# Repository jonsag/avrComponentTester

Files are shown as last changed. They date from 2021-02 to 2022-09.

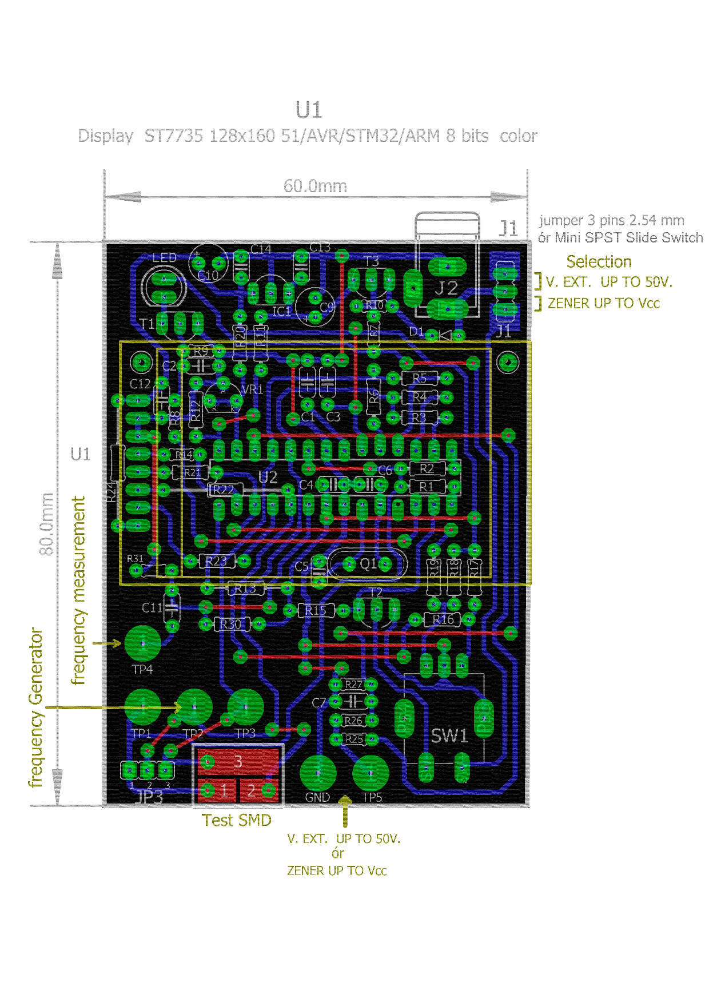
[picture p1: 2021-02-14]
Documents/PCB_mega328_ST7735/PCB single sided.jpg

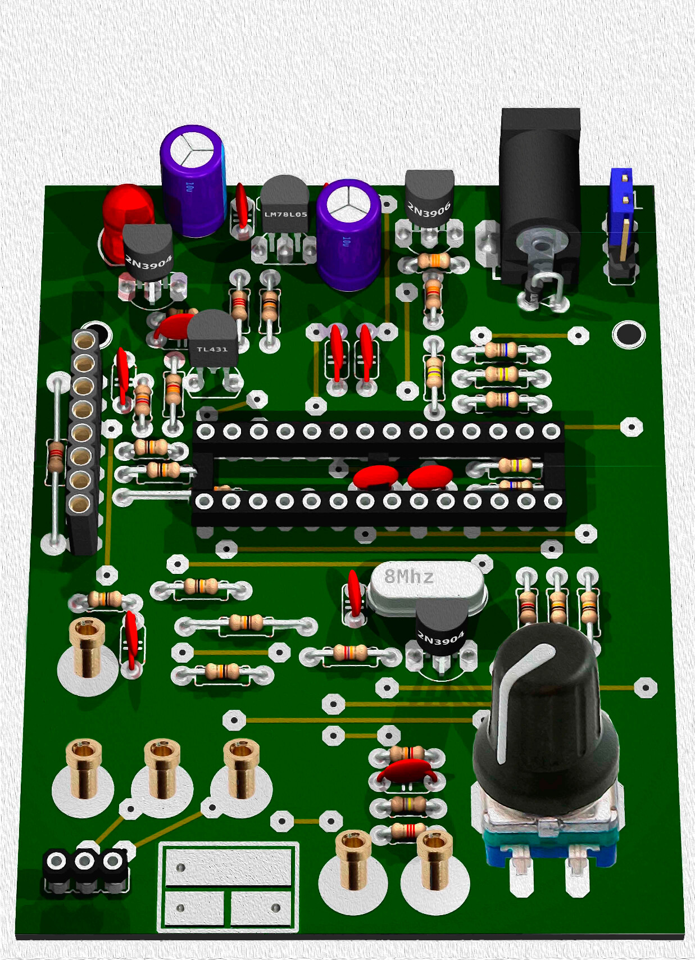
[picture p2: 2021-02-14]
Documents/PCB_mega328_ST7735/Image2.jpg

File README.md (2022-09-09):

# avrComponentTester

Adapted from project at [https://www.mikrocontroller.net/articles/AVR_Transistortester](https://www.mikrocontroller.net/articles/AVR_Transistortester)

## Download repository

>$ git clone [https://github.com/jonsag/avrComponentTester.git](https://github.com/jonsag/avrComponentTester.git)

## Hardware

### Programmer

You will need an avr programmer like [this one](https://github.com/jonsag/USBaspProgrammer), or perhaps [this one](https://github.com/jonsag/ardAVRProgrammer).  

I'm using the first of these two.  
If you use an another programmer you will have to adapt the avrdude -c switch in the commands below, and change some lines in the Makefile.  

### Components tester

Look in directory  

    KiCAD/avrComponentTester

There you will find schematics and PCB layout.  

## Software

### Prerequisites

#### Install and prepare avrdude

>$ sudo apt install make binutils-avr avrdude avr-libc gcc-avr cross-avr-gcc9  
>
>$ usermod -a -G dialout,plugdev $USER  

You have to log out user to make new groups available.  

### ATmega328P with ST7735 1.8" OLED screen

#### Adapt software

In mega328_color_kit/Makefile, uncomment line to change direction of the rotary encoder  

    #CFLAGS += -DCHANGE_ROTARY_DIRECTION

->

    CFLAGS += -DCHANGE_ROTARY_DIRECTION

To use USBASP Programmer comment three lines  

    PROGRAMMER=avrispmkII
    BitClock=1.0
    PORT=usb

->

    PROGRAMMER=avrispmkII
    BitClock=1.0
    PORT=usb

and instead uncomment these three lines  

    #PROGRAMMER=usbasp
    #BitClock=20
    #PORT=usb

->

    PROGRAMMER=usbasp
    BitClock=20
    PORT=usb

In autoconf.h, modify two lines:  

    #define R_L_VAL 6800
    ...
    #define R_H_VAL 47000

Set values to match your resistors, ie:  

    #define R_L_VAL 6790
    ...
    #define R_H_VAL 46900

#### Tester software

>$ cd \<PATH_TO>/Software/ATmega328p_with_st7735/mega328_color_kit
>
>$ make upload

Write fuses  

>$ make fuses-crystal

Clean up  

>$ make clean

#### Alternative method

Compile software  

>$ make

This creates four new files:  

    mega328_color_kit.eep
    mega328_color_kit.hex
    mega328_color_kit.lss
    mega328_color_kit.map

and a directory with lots of files in:

    ../Obj/

Upload software and EEPROM

>$ avrdude -p m328p -P usb -c usbasp -B 20 -v -U flash:w:mega328_color_kit.hex -U eeprom:w:mega328_color_kit.eep

Set fuses  

>$ avrdude -p m328p -P usb -c usbasp -B 20 -v -U lfuse:w:0xF7:m -U hfuse:w:0xD9:m -U efuse:w:0xFC:m

Clean up  

>$ make clean

## Resources

### Fuse bits

Fuse bit calculator [here](https://www.engbedded.com/fusecalc/).  

Some reading [here](https://embedds.com/all-you-need-to-know-about-avr-fuses/).  

### avrdude

Some avrdude switches:

    -p partno; what type of part that is connected to the programmer
    -P port; port to identify the device to which the programmer is attached
    -c programmer-id; the programmer to be used
    -b baudrate; override the RS-232 connection baud rate
    -e ; causes a chip erase to be executed
    -F ; override device signature check
    -B bitclock; specify the bit clock period for the JTAG interface or the ISP clock
    -D ; disable auto erase for flash
    -v ; enable verbose output, more -v options increase verbosity level
    -U <memtype:op:filename[:format]>
        flash; the flash ROM of the device
            w; read the specified file and write it to the specified device memory
        lock; the lock byte
        efuse; the extended fuse byte
        hfuse; the high fuse byte
        lfuse; the low fuse byte
        boot; the boot flash area of ATxmega devices
    -t ; enter the interactive “terminal” mode

More on [this page](https://www.nongnu.org/avrdude/user-manual/avrdude_4.html).  

#### Erase avr flash memory

>$ avrdude -p m328p -P usb -c usbasp -B 20 -v -e

or  

>$ avrdude -p m328p -P usb -c usbasp -B 20 -v -t

    avrdude: AVR device initialized and ready to accept instructions

    Reading | ################################################## | 100% 0.08s

    avrdude: Device signature = 0x1e950f (probably m328p)
    avrdude> erase
    >>> erase 
    avrdude: erasing chip
    avrdude> quit
    >>> quit 

    avrdude: safemode: Fuses OK (E:FD, H:DF, L:FF)

    avrdude done.  Thank you.

#### Read from MCU to file

Read flash  

>$ avrdude -p m328p -P usb -c usbasp -B 20 -v -U flash:r:flash.hex:i  

Read EEPROM  

>$ avrdude -p m328p -P usb -c usbasp -B 20 -v -U eeprom:r:eeprom.eep:i  

Read fuse bits  

>$ avrdude -p m328p -P usb -c usbasp -B 20 -U lfuse:r:-:i -U hfuse:r:-:i -U efuse:r:-:i

#### Bootloader

Build bootloader  

>$ cd \<PATH_TO>/Bootloader/optiboot
>
>$ make atmega328p AVR_FREQ=8000000 BAUD_RATE=9600 LED_START_FLASHES=0 LED_DATA_FLASH=1

Now you got six new files:  

    baudcheck.tmp.sh
    optiboot_atmega328p.hex
    optiboot_atmega328p.log
    optiboot/optiboot_atmega328p.lst
    optiboot.elf
    optiboot.o

Burn bootloader  

>$ avrdude -p m328p -P usb -c usbasp -B 20 -v -U flash:w:optiboot_atmega328p.hex:i

Clean up  

>$ make clean

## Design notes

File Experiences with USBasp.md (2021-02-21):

# Experiencews with USBasp programmer

## ATmega328P factory settings

Probably  

    LFuse = 0x62  
    HFuse = 0xD9  
    EFuse = 0xFF  
    Lock byte = 0xFF  
    Clock calibration = 0x95

## Testing a chip previously programmed

>$ cu -l /dev/ttyACM0 -s 115200

    Atmega chip detector.
    Written by Nick Gammon.
    Version 1.20
    Compiled on Feb 15 2021 at 16:17:48 with Arduino IDE 10813.
    Attempting to enter ICSP programming mode ...
    Entered programming mode OK.
    Signature = 0x1E 0x95 0x0F 
    Processor = ATmega328P
    Flash memory size = 32768 bytes.
    LFuse = 0xF7 
    HFuse = 0xD9 
    EFuse = 0xFC 
    Lock byte = 0xFF 
    Clock calibration = 0x8C 
    Bootloader in use: No
    EEPROM preserved through erase: No
    Watchdog timer always on: No
    Bootloader is 4096 bytes starting at 7000

    Bootloader:

    7000: 0xFF 0x92 0xFC 0x01 0x4C 0x01 0xA1 0x2C 0xB1 0x2C 0x74 0x01 0xDD 0x24 0xCC 0x24 
    ...
    7FF0: 0xFF 0xFF 0xFF 0xFF 0xFF 0xFF 0xFF 0xFF 0xFF 0xFF 0xFF 0xFF 0xFF 0xFF 0xFF 0xFF 

    MD5 sum of bootloader = 0x3B 0xE4 0xDB 0x3F 0x50 0x38 0x57 0x15 0xDB 0x46 0xD3 0xAB 0xC4 0x97 0x3A 0x95 
    Bootloader MD5 sum not known.

    First 256 bytes of program memory:

    00: 0xB9 0xC6 0x00 0x00 0xC9 0xC6 0x00 0x00 0xC7 0xC6 0x00 0x00 0xC5 0xC6 0x00 0x00
    ...
    F0: 0xC4 0xB8 0x84 0xFF 0x1A 0xC0 0xA8 0xE1 0x00 0x00 0xAA 0x95 0xF1 0xF7 0xEF 0x93 

    Programming mode off.

Fuses are now  

    LFuse = 0xF7 
    HFuse = 0xD9 
    EFuse = 0xFC 
    Lock byte = 0xFF 
    Clock calibration = 0x8C

## Trying to read chip with USBasp

Chip must have 8Mhz crystal on pins 9 and 10.

>$ avrdude -p m328p -P usb -c usbasp -B 20 -v -U flash:r:flash.hex:i -U eeprom:r:eeprom.eep:i

Diffs  

>$ diff mega328_color_kit.hex flash.hex | wc -l

    3003

>$ diff mega328_color_kit.eep eeprom.eep | wc -l

    91

## Testing with some makes

>$ make verify

Produces an error  

>$ make clean
>
>$ make upload make

Fuses are now  

    ... Fuses OK (E:FC, H:D9, L:F7)

Runs OK  

>$ make verify

All is OK  

>$ make fuses-crystal

Fuses are now  

    ... Fuses OK (E:FC, H:D9, L:F7)

Setting other fuses

>$ make fuses

Now fuses are  

    ... Fuses OK (E:FC, H:D9, L:E2)

Setting back to crystal and verifying

>$ make fuses-crystal
>
>$ make verify

All is OK

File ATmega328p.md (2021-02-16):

# Exploration of the ATmega328P

## Hardware used

Atmega_board_detector at [https://github.com/jonsag/ardAVRProgrammer](https://github.com/jonsag/ardAVRProgrammer).

## ATmega328P MCU  

### Empty chip

    Signature = 0x1E 0x95 0x0F  
    Processor = ATmega328P  
    Flash memory size = 32768 bytes.  
    LFuse = 0x62  
    HFuse = 0xD9  
    EFuse = 0xFF  
    Lock byte = 0xFF  
    Clock calibration = 0x95  
    Bootloader in use: No  
    EEPROM preserved through erase: No  
    Watchdog timer always on: No  
    Bootloader is 4096 bytes starting at 7000  
    
    Bootloader:  
    
    7000: 0xFF ...  
    ...  
    7FF0: 0xFF ...  
    
    MD5 sum of bootloader = 0x6A 0xE5 0x9E 0x64 0x85 0x03 0x77 0xEE 0x54 0x70 0xC8 0x54 0x76 0x15 0x51 0xEA  
    No bootloader (all 0xFF)  
    
    First 256 bytes of program memory:  
    
    00: 0xFF ...  
    ...  
    F0: 0xFF ...  

### With bootloader from Arduino IDE

Board: Arduino AVR Boards -> Arduino Duemilanove or Diecimila  
Processor: ATmega328P  

    Signature = 0x1E 0x95 0x0F  
    Processor = ATmega328P  
    Flash memory size = 32768 bytes.  
    LFuse = 0xFF  
    HFuse = 0xDA  
    EFuse = 0xFD  
    Lock byte = 0xCF  
    Clock calibration = 0x95  
    Bootloader in use: Yes  
    EEPROM preserved through erase: No  
    Watchdog timer always on: No  
    Bootloader is 2048 bytes starting at 7800  
    
    Bootloader:  
    
    7800: 0x0C ...  
    ...  
    7FF0: 0xFF ...  
    
    MD5 sum of bootloader = 0x0A 0xAC 0xF7 0x16 0xF4 0x3C 0xA2 0xC9 0x27 0x7E 0x08 0xB9 0xD6 0x90 0xBC 0x02  
    Bootloader name: ATmegaBOOT_168_atmega328  
    
    First 256 bytes of program memory:  
    
    00: 0xFF ...  
    ...  
    F0: 0xFF ...  

Board: ATmega Microcontrollers -> ATmega328/328p  
Processor: ATmega328p  
Clock: Internal 8 MHz  

    Signature = 0x1E 0x95 0x0F  
    Processor = ATmega328P  
    Flash memory size = 32768 bytes.  
    LFuse = 0xE2  
    HFuse = 0xDB  
    EFuse = 0xFD  
    Lock byte = 0xFF  
    Clock calibration = 0x95  
    Bootloader in use: No  
    EEPROM preserved through erase: No  
    Watchdog timer always on: No  
    Bootloader is 2048 bytes starting at 7800  
    
    Bootloader:  
    
    7800: 0xFF ...  
    ...  
    7FF0: 0xFF ...  
    
    MD5 sum of bootloader = 0xE0 0xDE 0xEB 0xD3 0xC3 0xF5 0x60 0x21 0x2A 0xF1 0x7C 0x68 0xB9 0x34 0x4B 0xAE  
    No bootloader (all 0xFF)  
    
    First 256 bytes of program memory:  
    
    00: 0xFF ...  
    ...  
    F0: 0xFF ...  

Board: ATmega168/328 -> ATmega168/328  
Micro: ATmega328P @ 16MHz w/Arduino as ISP (Optiboot)  
(produces an error on burning)  

    Signature = 0x1E 0x95 0x0F  
    Processor = ATmega328P  
    Flash memory size = 32768 bytes.  
    LFuse = 0xFF  
    HFuse = 0xDE  
    EFuse = 0xFD  
    Lock byte = 0xCF  
    Clock calibration = 0x95  
    Bootloader in use: Yes  
    EEPROM preserved through erase: No  
    Watchdog timer always on: No  
    Bootloader is 512 bytes starting at 7E00  
    
    Bootloader:  
    
    7E00: 0x11 ...  
    ...  
    7FF0: 0xFF ...  
    
    MD5 sum of bootloader = 0xFB 0xF4 0x9B 0x7B 0x59 0x73 0x7F 0x65 0xE8 0xD0 0xF8 0xA5 0x08 0x12 0xE7 0x9F  
    Bootloader name: optiboot_atmega328  
    
    First 256 bytes of program memory:  
    
    00: 0xFF ...  
    ...  
    F0: 0xFF ...  

Board: ATmega168/328 -> ATmega168/328  
Micro: ATmega328P @ 16MHz w/Arduino as ISP  
(produces an error on burning)  

    Signature = 0x1E 0x95 0x0F  
    Processor = ATmega328P  
    Flash memory size = 32768 bytes.  
    LFuse = 0xFF  
    HFuse = 0xDF  
    EFuse = 0xFD  
    Lock byte = 0xCF  
    Clock calibration = 0x95  
    Bootloader in use: No  
    EEPROM preserved through erase: No  
    Watchdog timer always on: No  
    Bootloader is 512 bytes starting at 7E00  
    
    Bootloader:  
    
    7E00: 0x11 ...  
    ...  
    7FF0: 0xFF ...  
    
    MD5 sum of bootloader = 0xFB 0xF4 0x9B 0x7B 0x59 0x73 0x7F 0x65 0xE8 0xD0 0xF8 0xA5 0x08 0x12 0xE7 0x9F  
    Bootloader name: optiboot_atmega328  
    
    First 256 bytes of program memory:  
    
    00: 0xFF ...  
    ...  
    F0: 0xFF ...  

### With bootloader from Bootloader/optiboot

Compile bootloader  

>$ cd Bootloader/optiboot
>
>$ make atmega328p AVR_FREQ=8000000 BAUD_RATE=9600 LED_START_FLASHES=0 LED_DATA_FLASH=1

    Optiboot for 8000000 Hz (8.00 Mhz) operation with Baudrate 9600 and EEprom support configured.
     >>> Start building optiboot for AVR atmega328p:
    LED-Pin PB5 use Pin 19-PDIP28 17-TQFP32, with special functions: SCK PCINT5.
    RX-Pin PD0 use Pin 2-PDIP28 30-TQFP32, with special functions: PCINT16 RXD.
    TX-Pin PD1 use Pin 3-PDIP28 31-TQFP32, with special functions: PCINT17 TXD.
    avr-gcc -g -Wall -Os -fno-split-wide-types -mrelax -mmcu=atmega328p  -fno-diagnostics-show-caret -DBAUD_RATE=9600 -DLED_START_FLASHES=0 -DLED_DATA_FLASH=1 -DSUPPORT_EEPROM=1 -DLED=pB5 -DUART=00 -DSOFT_UART=0 -DUART_RX=pD0 -DUART_TX=pD1 -DF_CPU=8000000 -DHFUSE=hexDE -DLFUSE=hexFF -DBOOT_PAGE_LEN=512 -DVerboseLev=2 -c -o optiboot.o optiboot.S

    --------------------------------------------------------------------------------
    BAUD RATE CHECK: Desired: 9600,  Real: 9615.3, UBRR = 103, Difference=.16%
    --------------------------------------------------------------------------------
    # # # # # # # # # # # # # # # # # # # # # #
    Boot Loader start address: 0x7E00 = 32256
    # # # # # # # # # # # # # # # # # # # # # #

       text	   data	    bss	    dec	    hex	filename
        436	      0	      0	    436	    1b4	optiboot.elf
    Requires 1 Boot Page of 512 Bytes, which is 1.5% of Flash Memory
    BOOTSZ=3, which means 1 Boot Page

Upload bootloader  

>$ avrdude -p m328p -P /dev/ttyUSB0 -c avrisp -b 19200 -v -U flash:w:optiboot_atmega328p.hex:i

    avrdude: Version 6.3
             Copyright (c) 2000-2005 Brian Dean, http://www.bdmicro.com/
             Copyright (c) 2007-2014 Joerg Wunsch

             System wide configuration file is "/etc/avrdude.conf"
             User configuration file is "/home/jon/.avrduderc"
             User configuration file does not exist or is not a regular file, skipping

             Using Port                    : /dev/ttyUSB0
             Using Programmer              : avrisp
             Overriding Baud Rate          : 19200
             AVR Part                      : ATmega328P
             Chip Erase delay              : 9000 us
             PAGEL                         : PD7
             BS2                           : PC2
             RESET disposition             : dedicated
             RETRY pulse                   : SCK
             serial program mode           : yes
             parallel program mode         : yes
             Timeout                       : 200
             StabDelay                     : 100
             CmdexeDelay                   : 25
             SyncLoops                     : 32
             ByteDelay                     : 0
             PollIndex                     : 3
             PollValue                     : 0x53
             Memory Detail                 :

                                      Block Poll               Page                       Polled
               Memory Type Mode Delay Size  Indx Paged  Size   Size #Pages MinW  MaxW   ReadBack
               ----------- ---- ----- ----- ---- ------ ------ ---- ------ ----- ----- ---------
               eeprom        65    20     4    0 no       1024    4      0  3600  3600 0xff 0xff
               flash         65     6   128    0 yes     32768  128    256  4500  4500 0xff 0xff
               lfuse          0     0     0    0 no          1    0      0  4500  4500 0x00 0x00
               hfuse          0     0     0    0 no          1    0      0  4500  4500 0x00 0x00
               efuse          0     0     0    0 no          1    0      0  4500  4500 0x00 0x00
               lock           0     0     0    0 no          1    0      0  4500  4500 0x00 0x00
               calibration    0     0     0    0 no          1    0      0     0     0 0x00 0x00
               signature      0     0     0    0 no          3    0      0     0     0 0x00 0x00

             Programmer Type : STK500
             Description     : Atmel AVR ISP
             Hardware Version: 2
             Firmware Version: 1.18
             Topcard         : Unknown
             Vtarget         : 0.0 V
             Varef           : 0.0 V
             Oscillator      : Off
             SCK period      : 0.1 us

    avrdude: AVR device initialized and ready to accept instructions

    Reading | ################################################## | 100% 0.08s

    avrdude: Device signature = 0x1e950f (probably m328p)
    avrdude: safemode: hfuse reads as DF
    avrdude: safemode: efuse reads as FD
    avrdude: NOTE: "flash" memory has been specified, an erase cycle will be performed
             To disable this feature, specify the -D option.
    avrdude: erasing chip
    avrdude: reading input file "optiboot_atmega328p.hex"
    avrdude: writing flash (32768 bytes):

    Writing | ################################################## | 100% 0.00s

    avrdude: 32768 bytes of flash written
    avrdude: verifying flash memory against optiboot_atmega328p.hex:
    avrdude: load data flash data from input file optiboot_atmega328p.hex:
    avrdude: input file optiboot_atmega328p.hex contains 32768 bytes
    avrdude: reading on-chip flash data:

    Reading | ################################################## | 100% 0.00s

    avrdude: verifying ...
    avrdude: 32768 bytes of flash verified

    avrdude: safemode: hfuse reads as DF
    avrdude: safemode: efuse reads as FD
    avrdude: safemode: Fuses OK (E:FD, H:DF, L:FF)

    avrdude done.  Thank you.

I interpret this as:  

    lfuse: 0xFF
    hfuse: 0xDF
    efuse: 0xFD

Testing with Board Detector  

    Signature = 0x1E 0x95 0x0F 
    Processor = ATmega328P
    Flash memory size = 32768 bytes.
    LFuse = 0xFF 
    HFuse = 0xDF 
    EFuse = 0xFD 
    Lock byte = 0xFF 
    Clock calibration = 0x95 
    Bootloader in use: No
    EEPROM preserved through erase: No
    Watchdog timer always on: No
    Bootloader is 512 bytes starting at 7E00

    Bootloader:

    7E00: 0xF8 ...
    ...
    7FF0: 0xFF ...

    MD5 sum of bootloader = 0xB0 0xF1 0xD0 0xF8 0xEB 0x10 0x10 0xAC 0x95 0xCB 0x7E 0x8F 0x04 0x0D 0xFA 0xA2 
    Bootloader MD5 sum not known.

    First 256 bytes of program memory:

    00: 0xFF ...
    ...
    F0: 0xFF ...

Trying with different baudrate  

>$ make atmega328p AVR_FREQ=8000000 BAUD_RATE=19200 LED_START_FLASHES=0 LED_DATA_FLASH=1

    Optiboot for 8000000 Hz (8.00 Mhz) operation with Baudrate 19200 and EEprom support configured.
     >>> Start building optiboot for AVR atmega328p:
    LED-Pin PB5 use Pin 19-PDIP28 17-TQFP32, with special functions: SCK PCINT5.
    RX-Pin PD0 use Pin 2-PDIP28 30-TQFP32, with special functions: PCINT16 RXD.
    TX-Pin PD1 use Pin 3-PDIP28 31-TQFP32, with special functions: PCINT17 TXD.
    avr-gcc -g -Wall -Os -fno-split-wide-types -mrelax -mmcu=atmega328p  -fno-diagnostics-show-caret -DBAUD_RATE=19200 -DLED_START_FLASHES=0 -DLED_DATA_FLASH=1 -DSUPPORT_EEPROM=1 -DLED=pB5 -DUART=00 -DSOFT_UART=0 -DUART_RX=pD0 -DUART_TX=pD1 -DF_CPU=8000000 -DHFUSE=hexDE -DLFUSE=hexFF -DBOOT_PAGE_LEN=512 -DVerboseLev=2 -c -o optiboot.o optiboot.S

    --------------------------------------------------------------------------------
    BAUD RATE CHECK: Desired: 19200,  Real: 19230, UBRR = 51, Difference=.16%
    --------------------------------------------------------------------------------
    # # # # # # # # # # # # # # # # # # # # # #
    Boot Loader start address: 0x7E00 = 32256
    # # # # # # # # # # # # # # # # # # # # # #

       text	   data	    bss	    dec	    hex	filename
        436	      0	      0	    436	    1b4	optiboot.elf
    Requires 1 Boot Page of 512 Bytes, which is 1.5% of Flash Memory
    BOOTSZ=3, which means 1 Boot Page

Uploading  

>$ avrdude -p m328p -P /dev/ttyUSB0 -c avrisp -b 19200 -v -U flash:w:optiboot_atmega328p.hex:i

Board detector:

    Signature = 0x1E 0x95 0x0F  
    Processor = ATmega328P  
    Flash memory size = 32768 bytes.  
    LFuse = 0xFF  
    HFuse = 0xDF  
    EFuse = 0xFD  
    Lock byte = 0xFF  
    Clock calibration = 0x95  
    Bootloader in use: No  
    EEPROM preserved through erase: No  
    Watchdog timer always on: No  
    Bootloader is 512 bytes starting at 7E00  
    
    Bootloader:  
    
    7E00: 0xF8 ...  
    ...  
    7FF0: 0xFF ...  
    
    MD5 sum of bootloader = 0x7C 0xC0 0x57 0xDA 0x91 0xA6 0x82 0x30 0x6A 0x9D 0x6A 0x96 0xD1 0xFF 0xBA 0xD6  
    Bootloader MD5 sum not known.  
    
    First 256 bytes of program memory:  
    
    00: 0xFF ...  
    ...  
    F0: 0xFF ...  

### Erasing chip and uploading software

>$ avrdude -p m328p -P /dev/ttyUSB0 -c avrisp -b 19200 -e  
>  
>$ cd Software/ATmega328p_with_st7735/mega328_color_kit  
>  
>$ make  

    rm -rf ../Obj/mega328_color_kit
    mkdir ../Obj/mega328_color_kit
    mkdir ../Obj/mega328_color_kit/dep
    avr-gcc  -Wall ...
    ...
    avr-objdump -h -S ../Obj/mega328_color_kit/mega328_color_kit.elf > mega328_color_kit.lss

    8 MHz operation configured.
    AVR Memory Usage
    ----------------
    Device: atmega328p

    Program:   31980 bytes (97.6% Full)
    (.text + .data + .bootloader)

    Data:        204 bytes (10.0% Full)
    (.data + .bss + .noinit)

    EEPROM:      876 bytes (85.5% Full)
    (.eeprom)

>$ avrdude -p m328p -P /dev/ttyUSB0 -c avrisp -b 19200 -U flash:w:mega328_color_kit.hex  

    avrdude: AVR device initialized and ready to accept instructions

    Reading | ################################################## | 100% 0.08s

    avrdude: Device signature = 0x1e950f (probably m328p)
    avrdude: NOTE: "flash" memory has been specified, an erase cycle will be performed
            To disable this feature, specify the -D option.
    avrdude: erasing chip
    avrdude: reading input file "mega328_color_kit.hex"
    avrdude: input file mega328_color_kit.hex auto detected as Intel Hex
    avrdude: writing flash (31980 bytes):

    Writing | ################################################## | 100% 39.85s

    avrdude: 31980 bytes of flash written
    avrdude: verifying flash memory against mega328_color_kit.hex:
    avrdude: load data flash data from input file mega328_color_kit.hex:
    avrdude: input file mega328_color_kit.hex auto detected as Intel Hex
    avrdude: input file mega328_color_kit.hex contains 31980 bytes
    avrdude: reading on-chip flash data:

    Reading | ################################################## | 100% 31.26s

    avrdude: verifying ...
    avrdude: 31980 bytes of flash verified

    avrdude: safemode: Fuses OK (E:FD, H:DF, L:FF)

    avrdude done.  Thank you.

Checking with Board Detector:

    Signature = 0x1E 0x95 0x0F 
    Processor = ATmega328P
    Flash memory size = 32768 bytes.
    LFuse = 0xFF 
    HFuse = 0xDF 
    EFuse = 0xFD 
    Lock byte = 0xFF 
    Clock calibration = 0x95 
    Bootloader in use: No
    EEPROM preserved through erase: No
    Watchdog timer always on: No
    Bootloader is 512 bytes starting at 7E00

    Bootloader:

    7E00: 0xFF ...
    ...
    7FF0: 0xFF ...

    MD5 sum of bootloader = 0xDE 0x03 0xFE 0x65 0xA6 0x76 0x5C 0xAA 0x8C 0x91 0x34 0x3A 0xCC 0x62 0xCF 0xFC 
    No bootloader (all 0xFF)

    First 256 bytes of program memory:

    00: 0xB9 ...
    ...
    F0: 0xC4 ...

### Erasing chip, burning bootloader and uploading software

>$ avrdude -p m328p -P /dev/ttyUSB0 -c avrisp -b 19200 -e  
>
>$ cd Bootloader/optiboot
>
>$ make atmega328p AVR_FREQ=8000000 BAUD_RATE=9600 LED_START_FLASHES=0 LED_DATA_FLASH=1
>
>$ avrdude -p m328p -P /dev/ttyUSB0 -c avrisp -b 19200 -v -U flash:w:optiboot_atmega328p.hex:i
>
>$ cd Software/ATmega328p_with_st7735/mega328_color_kit
>
>$ make
>
>$ avrdude -p m328p -P /dev/ttyUSB0 -c avrisp -b 19200 -v -U flash:w:mega328_color_kit.hex

Checking with Board Detector:  

    Signature = 0x1E 0x95 0x0F 
    Processor = ATmega328P
    Flash memory size = 32768 bytes.
    LFuse = 0xFF 
    HFuse = 0xDF 
    EFuse = 0xFD 
    Lock byte = 0xFF 
    Clock calibration = 0x95 
    Bootloader in use: No
    EEPROM preserved through erase: No
    Watchdog timer always on: No
    Bootloader is 512 bytes starting at 7E00

    Bootloader:

    7E00: 0xFF ...
    ...
    7FF0: 0xFF ...

    MD5 sum of bootloader = 0xDE 0x03 0xFE 0x65 0xA6 0x76 0x5C 0xAA 0x8C 0x91 0x34 0x3A 0xCC 0x62 0xCF 0xFC 
    No bootloader (all 0xFF)

    First 256 bytes of program memory:

    00: 0xB9 ...
    ...
    F0: 0xC4 ...

Evidently this erases the bootloader

Trying again with -D switch  

>$ avrdude -p m328p -P /dev/ttyUSB0 -c avrisp -b 19200 -e  
>
>$ avrdude -p m328p -P /dev/ttyUSB0 -c avrisp -b 19200 -v -U flash:w:optiboot_atmega328p.hex:i
>
>$ avrdude -p m328p -P /dev/ttyUSB0 -c avrisp -b 19200 -v -D -U flash:w:mega328_color_kit.hex

Checking with Board Detector:  

    Signature = 0x1E 0x95 0x0F 
    Processor = ATmega328P
    Flash memory size = 32768 bytes.
    LFuse = 0xFF 
    HFuse = 0xDF 
    EFuse = 0xFD 
    Lock byte = 0xFF 
    Clock calibration = 0x95 
    Bootloader in use: No
    EEPROM preserved through erase: No
    Watchdog timer always on: No
    Bootloader is 512 bytes starting at 7E00

    Bootloader:

    7E00: 0xF8 ...
    ...
    7FF0: 0xFF ...

    MD5 sum of bootloader = 0xB0 0xF1 0xD0 0xF8 0xEB 0x10 0x10 0xAC 0x95 0xCB 0x7E 0x8F 0x04 0x0D 0xFA 0xA2 
    Bootloader MD5 sum not known.

    First 256 bytes of program memory:

    00: 0xB9 ...
    ...
    F0: 0xC4 ...

Now the bootloader stays  

### Setting fuses

>$ avrdude -p m328p -P /dev/ttyUSB0 -c avrisp -b 19200 -U lfuse:w:0xF7:m -U hfuse:w:0xD9:m -U efuse:w:0xFC:m

Checking with Board Detector:  

    Signature = 0x1E 0x95 0x0F 
    Processor = ATmega328P
    Flash memory size = 32768 bytes.
    LFuse = 0xF7 
    HFuse = 0xD9 
    EFuse = 0xFC 
    Lock byte = 0xFF 
    Clock calibration = 0x95 
    Bootloader in use: No
    EEPROM preserved through erase: No
    Watchdog timer always on: No
    Bootloader is 4096 bytes starting at 7000

    Bootloader:

    7000: 0xFF ...
    ...
    7FF0: 0xFF ...

    MD5 sum of bootloader = 0xAC 0x30 0xC1 0x8F 0x18 0x2B 0x1E 0x5D 0x92 0x81 0x06 0x75 0xD2 0x57 0x60 0x22 
    Bootloader MD5 sum not known.

    First 256 bytes of program memory:

    00: 0xB9 ...
    ...
    F0: 0xC4 ...

### Uploading with make

>$ avrdude -p m328p -P /dev/ttyUSB0 -c avrisp -b 19200 -e  
>
>$ avrdude -p m328p -P /dev/ttyUSB0 -c avrisp -b 19200 -v -U flash:w:optiboot_atmega328p.hex:i
>
>$ make upload make

    make
    make[1]: Entering directory '/home/jon/Documents/CodeWorkspace/avrComponentTester/Software/ATmega328p_with_st7735/mega328_color_kit'
    rm -rf ../Obj/mega328_color_kit
    mkdir ../Obj/mega328_color_kit
    mkdir ../Obj/mega328_color_kit/dep
    avr-gcc  -Wall ...
    ...
    avr-objdump -h -S ../Obj/mega328_color_kit/mega328_color_kit.elf > mega328_color_kit.lss

    8 MHz operation configured.
    AVR Memory Usage
    ----------------
    Device: atmega328p

    Program:   31980 bytes (97.6% Full)
    (.text + .data + .bootloader)

    Data:        204 bytes (10.0% Full)
    (.data + .bss + .noinit)

    EEPROM:      876 bytes (85.5% Full)
    (.eeprom)

    make[1]: Leaving directory '/home/jon/Documents/CodeWorkspace/avrComponentTester/Software/ATmega328p_with_st7735/mega328_color_kit'
    avrdude -c avrisp -B 1.0 -b 19200 -p m328p -P /dev/ttyUSB0 -U flash:w:./mega328_color_kit.hex:a \
    -U eeprom:w:./mega328_color_kit.eep:a

    avrdude: AVR device initialized and ready to accept instructions

    Reading | ################################################## | 100% 0.08s

    avrdude: Device signature = 0x1e950f (probably m328p)
    avrdude: NOTE: "flash" memory has been specified, an erase cycle will be performed
            To disable this feature, specify the -D option.
    avrdude: erasing chip
    avrdude: reading input file "./mega328_color_kit.hex"
    avrdude: input file ./mega328_color_kit.hex auto detected as Intel Hex
    avrdude: writing flash (31980 bytes):

    Writing | ################################################## | 100% 39.85s

    avrdude: 31980 bytes of flash written
    avrdude: verifying flash memory against ./mega328_color_kit.hex:
    avrdude: load data flash data from input file ./mega328_color_kit.hex:
    avrdude: input file ./mega328_color_kit.hex auto detected as Intel Hex
    avrdude: input file ./mega328_color_kit.hex contains 31980 bytes
    avrdude: reading on-chip flash data:

    Reading | ################################################## | 100% 31.26s

    avrdude: verifying ...
    avrdude: 31980 bytes of flash verified
    avrdude: reading input file "./mega328_color_kit.eep"
    avrdude: input file ./mega328_color_kit.eep auto detected as Intel Hex
    avrdude: writing eeprom (876 bytes):

    Writing | ################################################## | 100% 53.09s

    avrdude: 876 bytes of eeprom written
    avrdude: verifying eeprom memory against ./mega328_color_kit.eep:
    avrdude: load data eeprom data from input file ./mega328_color_kit.eep:
    avrdude: input file ./mega328_color_kit.eep auto detected as Intel Hex
    avrdude: input file ./mega328_color_kit.eep contains 876 bytes
    avrdude: reading on-chip eeprom data:

    Reading | ################################################## | 100% 13.51s

    avrdude: verifying ...
    avrdude: verification error, first mismatch at byte 0x0000
            0x20 != 0x49
    avrdude: verification error; content mismatch

    avrdude: safemode: Fuses OK (E:FC, H:D9, L:F7)

    avrdude done.  Thank you.

    ../finish.mk:174: recipe for target 'upload' failed
    make: *** [upload] Error 1

>$ make fuses-crystal

    avrdude -c avrisp -B 200 -b 19200 -p m328p -P /dev/ttyUSB0  -U lfuse:w:0xf7:m -U hfuse:w:0xd9:m -U efuse:w:0xfc:m

    avrdude: AVR device initialized and ready to accept instructions

    Reading | ################################################## | 100% 0.08s

    avrdude: Device signature = 0x1e950f (probably m328p)
    avrdude: reading input file "0xf7"
    avrdude: writing lfuse (1 bytes):

    Writing | ################################################## | 100% 0.03s

    avrdude: 1 bytes of lfuse written
    avrdude: verifying lfuse memory against 0xf7:
    avrdude: load data lfuse data from input file 0xf7:
    avrdude: input file 0xf7 contains 1 bytes
    avrdude: reading on-chip lfuse data:

    Reading | ################################################## | 100% 0.03s

    avrdude: verifying ...
    avrdude: 1 bytes of lfuse verified
    avrdude: reading input file "0xd9"
    avrdude: writing hfuse (1 bytes):

    Writing | ################################################## | 100% 0.03s

    avrdude: 1 bytes of hfuse written
    avrdude: verifying hfuse memory against 0xd9:
    avrdude: load data hfuse data from input file 0xd9:
    avrdude: input file 0xd9 contains 1 bytes
    avrdude: reading on-chip hfuse data:

    Reading | ################################################## | 100% 0.03s

    avrdude: verifying ...
    avrdude: 1 bytes of hfuse verified
    avrdude: reading input file "0xfc"
    avrdude: writing efuse (1 bytes):

    Writing | ################################################## | 100% 0.03s

    avrdude: 1 bytes of efuse written
    avrdude: verifying efuse memory against 0xfc:
    avrdude: load data efuse data from input file 0xfc:
    avrdude: input file 0xfc contains 1 bytes
    avrdude: reading on-chip efuse data:

    Reading | ################################################## | 100% 0.03s

    avrdude: verifying ...
    avrdude: 1 bytes of efuse verified

    avrdude: safemode: Fuses OK (E:FC, H:D9, L:F7)

    avrdude done.  Thank you.

Checking with Board Detector:  

    Signature = 0x1E 0x95 0x0F 
    Processor = ATmega328P
    Flash memory size = 32768 bytes.
    LFuse = 0xF7 
    HFuse = 0xD9 
    EFuse = 0xFC 
    Lock byte = 0xFF 
    Clock calibration = 0x95 
    Bootloader in use: No
    EEPROM preserved through erase: No
    Watchdog timer always on: No
    Bootloader is 4096 bytes starting at 7000

    Bootloader:

    7000: 0xFF ...
    ...
    7FF0: 0xFF ...

    MD5 sum of bootloader = 0x3B 0xE4 0xDB 0x3F 0x50 0x38 0x57 0x15 0xDB 0x46 0xD3 0xAB 0xC4 0x97 0x3A 0x95 
    Bootloader MD5 sum not known.

    First 256 bytes of program memory:

    00: 0xB9 ...
    ...
    F0: 0xC4 ...

### Erasing chip and uploading with just make upload make

>$ avrdude -p m328p -P /dev/ttyUSB0 -c avrisp -b 19200 -e  
>
>$ make upload make

Checking with Board Detector:  

    Signature = 0x1E 0x95 0x0F 
    Processor = ATmega328P
    Flash memory size = 32768 bytes.
    LFuse = 0xF7 
    HFuse = 0xD9 
    EFuse = 0xFC 
    Lock byte = 0xFF 
    Clock calibration = 0x95 
    Bootloader in use: No
    EEPROM preserved through erase: No
    Watchdog timer always on: No
    Bootloader is 4096 bytes starting at 7000

    Bootloader:

    7000: 0xFF ...
    ...
    7FF0: 0xFF ...

    MD5 sum of bootloader = 0x3B 0xE4 0xDB 0x3F 0x50 0x38 0x57 0x15 0xDB 0x46 0xD3 0xAB 0xC4 0x97 0x3A 0x95 
    Bootloader MD5 sum not known.

    First 256 bytes of program memory:

    00: 0xB9 ...
    ...
    F0: 0xC4 ...

Fuses stay and has bootloader.  

## Erase avr flash memory 

>$ avrdude -p m328p -P /dev/ttyUSB0 -c avrisp -b 19200 -e

or  

>$ avrdude -p m328p -P /dev/ttyUSB0 -c avrisp -b 19200 -t
>
>avrdude> erase

## Misc notes

Don't pay this any attention  

Fuse bits  

>$ avrdude -p m328p -P /dev/ttyUSB0 -c avrisp -b 19200 -v -e -U efuse:w:0x05:m -U hfuse:w:0xD6:m -U lfuse:w:0xFF:m

Hex file and lock bits  

>$ avrdude -p m328p -P /dev/ttyUSB0 -c avrisp -b 19200 -v -e -U flash:w:hexfilename.hex -U lock:w:0x0F:m

-U lock:w:0x0F:m -U lfuse:w:0xff:m -U hfuse:w:0xde:m -U efuse:w:0x05:m  

I tried to re-program a problematic GM328 that was not possible to calibrate.
https://www.youtube.com/watch?v=JCP7oWG3D3w
No matter what mega328_GM328 version I used from https://www.mikrocontroller.net/...
I always get a white blank screen.  The fuses I used are: lfuse=0xF7 hfuse=0xD9 efuse=0xFF

https://saturn.ffzg.hr/rot13/index.cgi?avr_component_tester
avrdude -c usbasp -B 20 -p m328p -P usb  -U lfuse:w:0xf7:m -U hfuse:w:0xd9:m -U efuse:w:0x04:m

https://github.com/blurpy/transistor-tester
fuses_lo = 0xf7
fuses_hi = 0xd9
fuses_ext = 0xfc
lock_byte = 0xff
I use a TL866II Plus universal programmer together with the minipro open source software for Linux. See https://github.com/blurpy/minipro for more about how to use.
With the chip in the programmer, just run these commands:
Erase chip: minipro -p "ATMEGA328P@DIP28" -E
Write eeprom: minipro -p "ATMEGA328P@DIP28" -c data -w ComponentTester.eep -e
Write flash: minipro -p "ATMEGA328P@DIP28" -c code -w ComponentTester.hex -e
Write fuses: minipro -p "ATMEGA328P@DIP28" -c config -w ComponentTester.cfg -e
That should be it.

$ make fuses-crystal
avrdude -c avrispmkII -B 200  -p m328p -P usb  -U lfuse:w:0xf7:m -U hfuse:w:0xd9:m -U efuse:w:0xfc:m

/home/jon/.arduino15/packages/arduino/tools/avrdude/6.3.0-arduino17/bin/avrdude \
-C/home/jon/.arduino15/packages/arduino/tools/avrdude/6.3.0-arduino17/etc/avrdude.conf \
-v -patmega328p \
-cstk500v1 \
-P/dev/ttyUSB0 \
-b19200 \
-Uflash:w:/tmp/arduino_build_677961/st7735_demo.ino.hex:i

>$ avrdude -v -patmega328p -cstk500v1 -P/dev/ttyUSB0 -b19200 -Uflash:w:

### make upload make

First erase chip  

>$ avrdude -p m328p -P /dev/ttyUSB0 -c avrisp -b 19200 -e

Compile and upload  

>$ cd \<PATH_TO>/Software/ATmega328p_with_st7735/mega328_color_kit
>
>$ make upload make

Commands run by this  

>$ make
>
>$ avrdude -c avrisp -B 1.0 -b 19200 -p m328p -P /dev/ttyUSB0 -U flash:w:./mega328_color_kit.hex:a \
>-U eeprom:w:./mega328_color_kit.eep:a

Upload of EEPROM failed.  

    avrdude: 876 bytes of eeprom written
    avrdude: verifying eeprom memory against ./mega328_color_kit.eep:
    avrdude: load data eeprom data from input file ./mega328_color_kit.eep:
    avrdude: input file ./mega328_color_kit.eep auto detected as Intel Hex
    avrdude: input file ./mega328_color_kit.eep contains 876 bytes
    avrdude: reading on-chip eeprom data:

    Reading | ################################################## | 100% 13.51s

    avrdude: verifying ...
    avrdude: verification error, first mismatch at byte 0x0000
            0x20 != 0x49
    avrdude: verification error; content mismatch

My compiled version of the .eep file are identical with the precompiled in the svn,  
and so is the .hex.  

Trying a dump of the .hex and .eep  

>$ avrdude -p m328p -P /dev/ttyUSB0 -c avrisp -b 19200 -v -U flash:r:flash.hex:i -U eeprom:r:eeprom.eep:i

Running diffs  

>$ diff mega328_color_kit.hex flash.hex | wc -l

    3003

>$ diff mega328_color_kit.eep eeprom.eep | wc -l

    91

Trying a new chip  

>$ make clean
>
>$ avrdude -p m328p -P /dev/ttyUSB0 -c avrisp -b 19200 -e
>
>$ make upload make
>
>$ avrdude -p m328p -P /dev/ttyUSB0 -c avrisp -b 19200 -v -U flash:r:flash2.hex:i -U eeprom:r:eeprom2.eep:i
>
>$ diff mega328_color_kit.hex flash2.hex | wc -l

    3003

>$ diff mega328_color_kit.eep eeprom2.eep | wc -l

    91

>$ make fuses-crystal

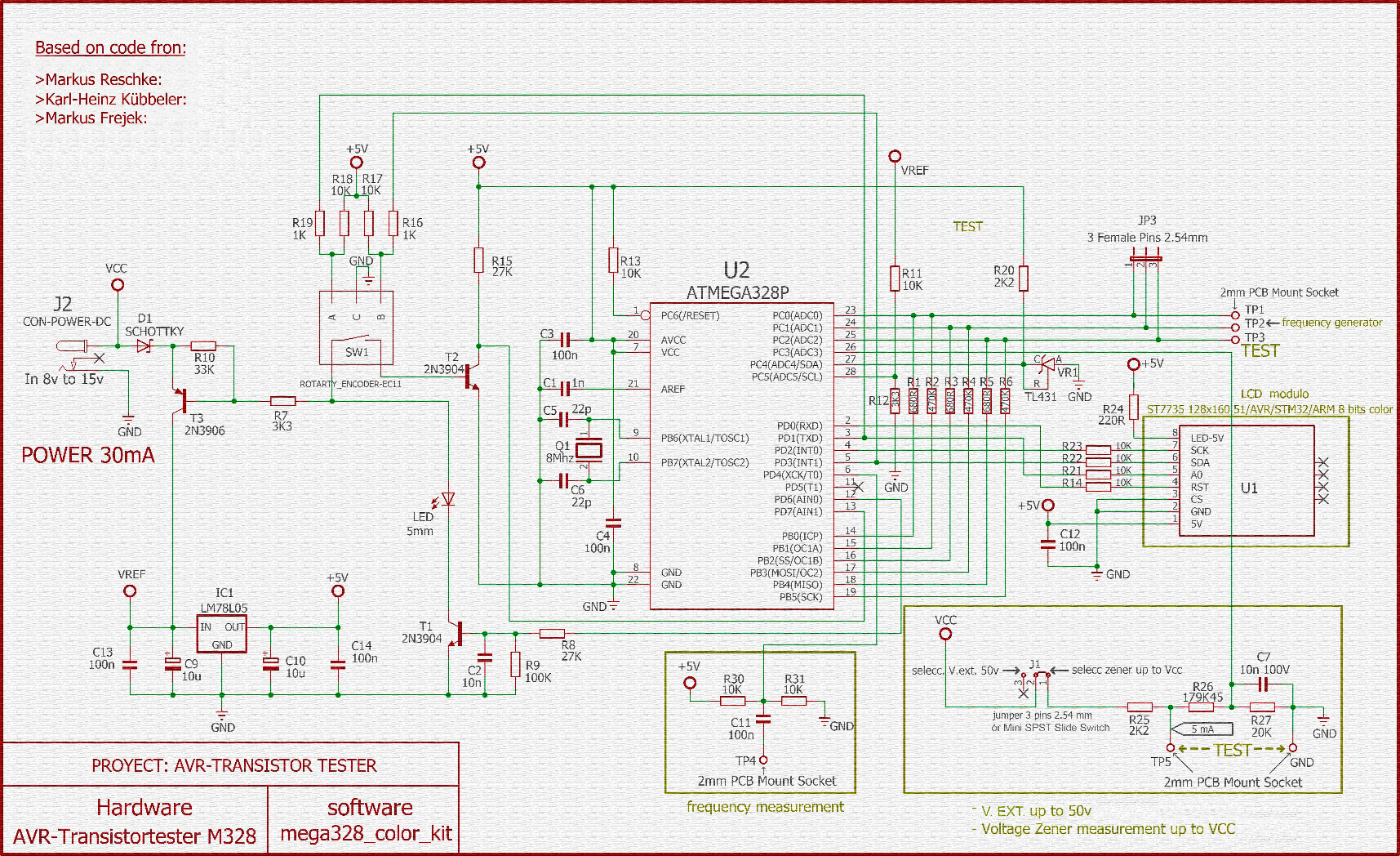
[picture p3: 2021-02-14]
Documents/PCB_mega328_ST7735/schematics.jpg

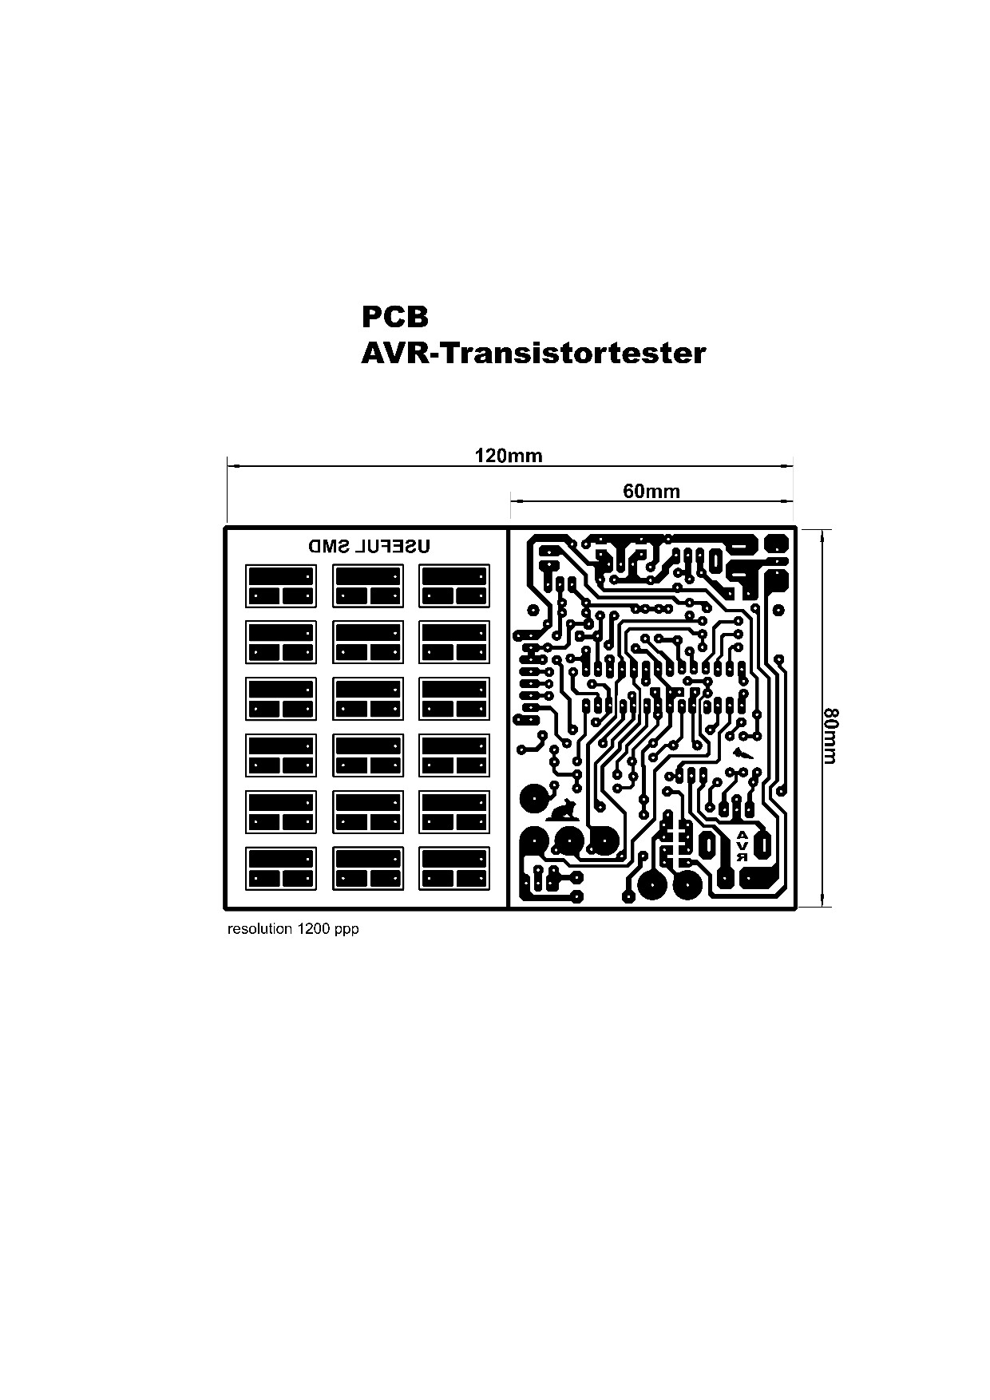
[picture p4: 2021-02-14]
Documents/PCB_mega328_ST7735/PCB mask.jpg

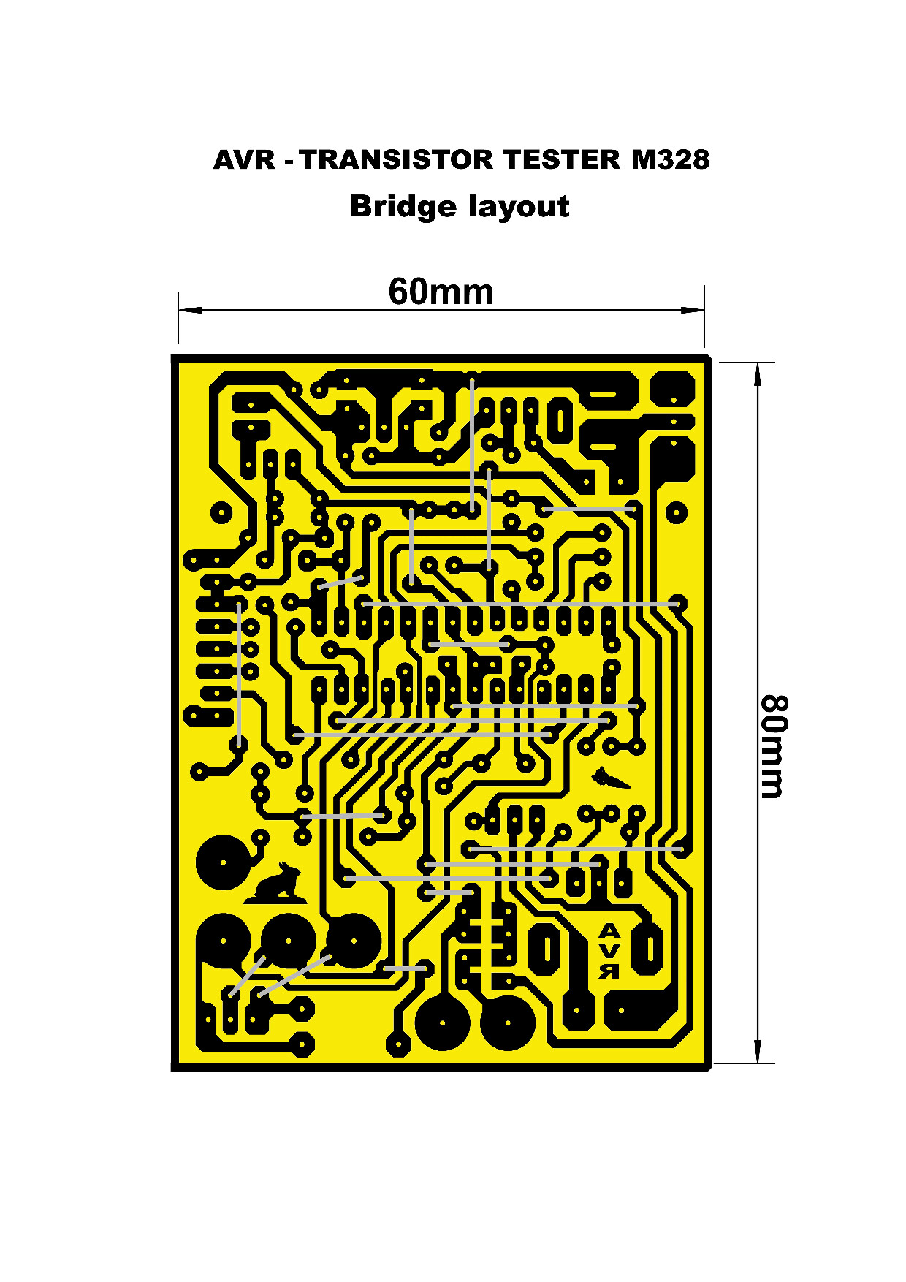
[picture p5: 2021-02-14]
Documents/PCB_mega328_ST7735/Bridge layout.jpg

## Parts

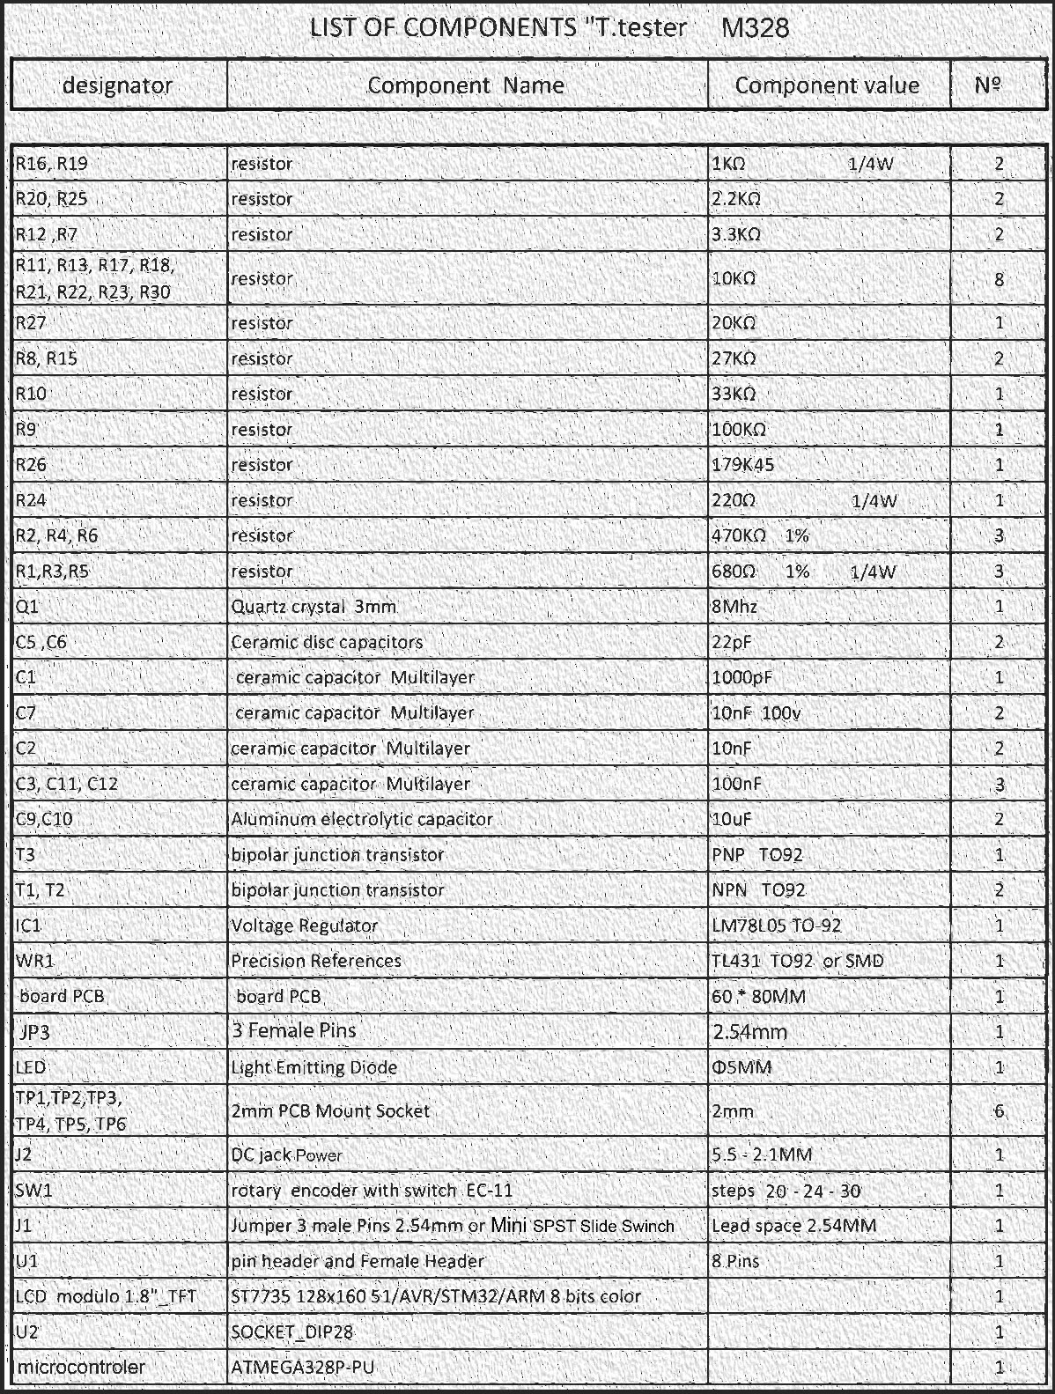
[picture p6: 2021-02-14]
Documents/PCB_mega328_ST7735/BOM.jpg

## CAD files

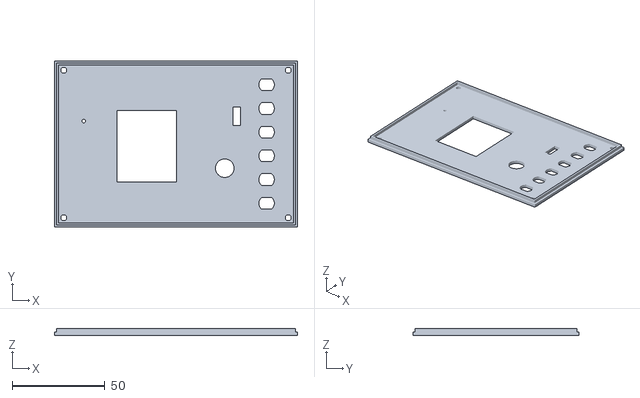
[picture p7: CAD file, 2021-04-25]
Casing/casing_lid.stl
131.1 x 89.6 x 4.00

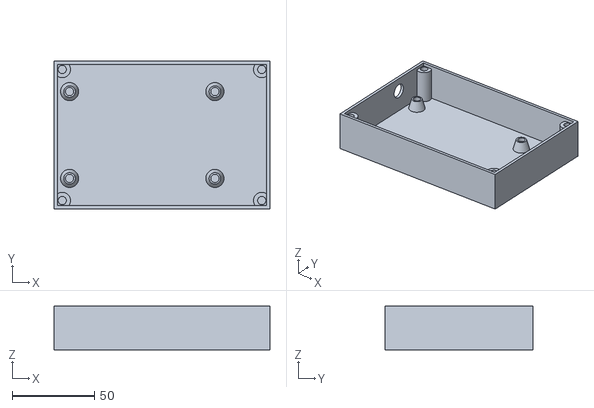
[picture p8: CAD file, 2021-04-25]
Casing/casing_bottom.stl
131.1 x 89.6 x 26.6

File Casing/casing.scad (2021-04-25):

// casing.scad

include <pcb.scad>
include <st7735.scad>

// layout for printing
print = true;

// what to show
showPCB = true;
showOLED = true;

showCaseBottom = false;
showCaseLid = true;

// PCB size
pcbX = 104.14;
pcbY = 61.59;
pcbZ = 1.6;

// case
caseWall = 2;

standoffHeight = 7;
standoffDia = 7;
standoffHole = 5;
standoffPos = [ [-pcbX / 2 + 4.45, -pcbY / 2 + 4.45],
		[-pcbX / 2 + 4.45, pcbY / 2 - 4.45],
		[pcbX / 2 - 11.45, -pcbY / 2 + 4.45],
		[pcbX / 2 - 11.45, pcbY / 2 - 4.45] ];

// power inlet
piDia = 10;

// rotary encoder
reHoleDia = 10;

// test jacks
tjDia = 8.33;
tjWidth = 6.35;

// case oversizes
osL = 3;
osR = 20;
osD = 12;
osU = 12;
osZ = 16;

// tolerance between case and lid
tolerance = 0.3;

// lid screws
lsStandDia = 10;
lsHoleDia = 5;
lsScrewHoleDia = 3.2;

// calculations
boxWidth = pcbX + osL + osR + caseWall * 2;
boxDepth = pcbY + osD + osU + caseWall * 2;
boxHeight = standoffHeight + pcbZ + osZ + caseWall;

boxOffsetX = (osR - osL) / 2;
boxOffsetY = (osU - osD) / 2;
boxOffsetZ = boxHeight / 2 - caseWall - standoffHeight;

// start drawing
if (showCaseBottom) {
  translate([boxOffsetX, boxOffsetY, boxOffsetZ])
  union() {
    // case bottom and walls
    color("azure", 1) {
	difference() {
	translate([0, 0, 0])
	  cube([boxWidth, boxDepth, boxHeight], center = true);
	translate([0, 0, caseWall])
	  cube([boxWidth - caseWall * 2, boxDepth - caseWall * 2, boxHeight], center = true);
	
	// power inlet
	translate([-boxWidth / 2 + caseWall / 2,
		   -boxDepth / 2 + 46.99 + osD + caseWall,
		   -boxHeight / 2 + caseWall + standoffHeight + pcbZ + 6.5])
	  rotate([0, 90, 0])
	  cylinder(h = caseWall * 2, d = piDia, center = true);
	}
    }
    // PCB standoffs
    for (i = standoffPos) {
      translate([i[0] - boxOffsetX,
		 i[1] - boxOffsetY,
		 -boxHeight / 2 + standoffHeight / 2 + caseWall])
	difference() {
	cylinder(h = standoffHeight, d1 = standoffDia + 4, d2 = standoffDia, center = true);
	cylinder(h = standoffHeight, d = standoffHole, center = true);
      }
    }

    // lid screw stands
    for (x = [-boxWidth / 2 + lsStandDia / 2, boxWidth / 2 - lsStandDia / 2]) {
      for (y = [-boxDepth / 2 + lsStandDia / 2 , boxDepth / 2 - lsStandDia / 2]) {
	translate([x, y, 0])
	difference() {
	  cylinder(h = boxHeight - caseWall * 2 - tolerance, d = lsStandDia, center = true);
	  cylinder(h = boxHeight, d = lsHoleDia, center = true);
	}
      }
    }
  }
 }

// lid
if (showCaseLid) {
  lidPosX = print ? boxOffsetX + boxWidth + 10 : boxOffsetX;
  lidPosY = print ? boxOffsetY : boxOffsetY;
  lidPosZ = print ? -boxHeight / 2 + boxOffsetZ + caseWall / 2: -caseWall / 2 - standoffHeight + boxHeight;
  lidRotateX = print ? 180 : 0;
  
  translate([lidPosX, lidPosY, lidPosZ])
    rotate([lidRotateX, 0, 0])
    union() {
    difference() {
      cube([boxWidth, boxDepth, caseWall], center = true);
      
      // rotary encoder hole
      translate([-pcbX / 2 + 86.88 - boxOffsetX, -pcbY / 2 + 43.85 - boxOffsetY, 0])
	cylinder(h = caseWall * 2, d = reHoleDia, center = true);
      
      // screen hole
      translate([-pcbX / 2 - boxOffsetX + 35.91 + 2.54 * 3.5, -pcbY / 2 + 32 - boxOffsetY, 0])
	cube([34 - 0.9 * 2, 38.5, caseWall * 2], center = true);
      
      // led hole
      translate([-pcbX / 2 + 10.79 - boxOffsetX, -pcbY / 2 + 18.41 - boxOffsetY, 0])
	cylinder(h = caseWall * 2, d = 2, center = true);
      
      // test socket
      translate([-pcbX / 2 - boxOffsetX + 93.34, -pcbY / 2 + 13.34 + 2.54 - boxOffsetY, 0])
	cube([4, 10, caseWall * 2], center = true);
      
      // test jacks
      for (y = [-boxDepth / 2 + boxDepth / 7: boxDepth / 7 : boxDepth / 2 - boxDepth / 7]) {
	translate([boxWidth / 2 - tjDia * 2, y, 0])
	intersection() {
	  cylinder(h = caseWall * 2, d = tjDia, center = true);
	  cube([tjDia, tjWidth, caseWall * 2], center = true);
	}
	// screw holes
	for (x = [-boxWidth / 2 + lsStandDia / 2, boxWidth / 2 - lsStandDia / 2]) {
	  for (y = [-boxDepth / 2 + lsStandDia / 2 , boxDepth / 2 - lsStandDia / 2]) {
	    translate([x, y, 0])
	      cylinder(h = caseWall * 3, d = lsScrewHoleDia, center = true);
	  }
	}
      }
    }
    
    // ridge under lid
    translate([0, 0, -caseWall])
      color("red")
      difference() {
      cube([boxWidth - caseWall - tolerance, boxDepth - caseWall - tolerance, caseWall], center = true);

      cube([boxWidth - caseWall * 2 - tolerance, boxDepth - caseWall * 2 - tolerance, caseWall * 2], center = true);
    }    
 }
 }
// pcb
if (showPCB && !print) {
  translate([0, 0, 0])
    difference() {                                                                
    let($show_threads = true)
      pcb(pcb);
    
    oledHoles();
    testOutlets();
  }
 }

// oled screen
if (showOLED && !print) {
  translate([-7.25, -1, 14.3])
    rotate([180, 0, 90])
    st7735v1(false);
 }

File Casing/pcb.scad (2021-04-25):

//
// NopSCADlib Copyright Chris Palmer 2020
// nop.head@gmail.com
// hydraraptor.blogspot.com
//
// This file is part of NopSCADlib.
//
// NopSCADlib is free software: you can redistribute it and/or modify it under the terms of the
// GNU General Public License as published by the Free Software Foundation, either version 3 of
// the License, or (at your option) any later version.
//
// NopSCADlib is distributed in the hope that it will be useful, but WITHOUT ANY WARRANTY;
// without even the implied warranty of MERCHANTABILITY or FITNESS FOR A PARTICULAR PURPOSE.
// See the GNU General Public License for more details.
//
// You should have received a copy of the GNU General Public License along with NopSCADlib.
// If not, see <https://www.gnu.org/licenses/>.
//

include <../../myCAD/OpenSCADlibraries/NopSCADlib/core.scad>
include <../../myCAD/OpenSCADlibraries/NopSCADlib/vitamins/leds.scad>

use <../../myCAD/OpenSCADlibraries/NopSCADlib/vitamins/pcb.scad>

pcb = ["avrComponentTester", "avrComponentTester",
	    104.14, 61.59, 1.6, // length, width, thickness
	    1,      // Corner radius
	    3.2,   // Mounting hole diameter
	    6.65,    // Pad around mounting hole
	    "green",// Color
	    true,   // True if the parts should be separate BOM items
	    // hole offsets, [lower left], [upper left], [lower right], [upper right]
	    [ [4.45, 4.45], [4.45, -4.45], [-11.45, 4.45], [-11.45, -4.45] ],
	    // components
	    [
	     [ 11.43 + 2.54,  58.42,   0, "2p54header", 3, 1],
	     [ 93.34,  13.34 + 2.54,   90, "2p54socket", 3, 1],
	     [ 35.91 + 2.54 * 3.5,  3.31,   0, "2p54socket", 8, 1],
	     [  10.79,  18.41,   0, "led", LED5mm, "red"],
	     [  4.45, 46.99, 180, "barrel_jack"],
	     [ 86.88, 43.85,   0, "potentiometer", 5, 8],
	     [ 40.01 + 2.54 * 1.5, 20.32 + 6.5 * 2.54,   180, "pdip", 28, "ATmega328P", true ],
	     ],
	    // accessories
	    []
	    ];

module oledHoles() {
  holes = [[30.48, 3.81],
	   [59.05, 3.81],
	   [59.05, 55.88],
	   [30.48, 55.88]];
  
  for(i = holes) {
    translate([-104.14 / 2 + i[0], -61.59 / 2 + i[1], -0.4 / 2])
      cylinder(h = 2, d = 3.2, $fn = 100);
  }
}

module testOutlets() {
    holes = [[99.06, 8.89],
	     [99.06, 15.24],
	     [99.06, 22.23],
	     [99.06, 41.27],
	     [99.06, 47.62],
	     [99.06, 53.98]];

  for(i = holes) {
    translate([-104.14 / 2 + i[0], -61.59 / 2 + i[1], -0.4 / 2])
      cylinder(h = 2, d = 3.2, $fn = 100);
  }
}

/*
if($preview) {
     difference() {
    let($show_threads = true)
      pcb(pcb);
    
    oledHoles();
    testOutlets();
    }
}
*/

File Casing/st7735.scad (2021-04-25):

// st7735.scad

include <../../myCAD/OpenSCADlibraries/NopSCADlib/core.scad>
include <../../myCAD/OpenSCADlibraries/NopSCADlib/vitamins/leds.scad>
include <../../myCAD/OpenSCADlibraries/NopSCADlib/vitamins/pin_headers.scad>

use <../../myCAD/OpenSCADlibraries/NopSCADlib/vitamins/pcb.scad>

st7735wSD = ["st7735wSD", "st7735wSD",
	     58, 34.2, 1.6, // length, width, thickness
	     1,      // Corner radius
	     3.2,   // Mounting hole diameter
	     5,    // Pad around mounting hole
	     "red",// Color                                                       
	     true,   // True if the parts should be separate BOM items
	     // hole offsets, [lower left], [upper left], [lower right], [upper right]
	     [ [3.1, 3.1], [3.1, -3.1], [-3.1, 3.1], [-3.1, -3.1] ],
            // components
	     [
	      [ 2.5,  34.2 / 2,   90, "2p54header", 8, 1],
	      ],
            // accessories
	     []
            ];

module st7735v1(sdPins = true) {
  pcb(st7735wSD);
  // OLED pins
  if (sdPins) {
    translate([58 / 2 - 2.5, 0, 1.6])
    rotate([0, 0, 90])
    pin_header(2p54header, 4, 1);
  }

  // screen
  translate([(51.4 - 50.3)  / 2, 0, 0]) {
  // screen frame
  translate([0, 0, -2.9 / 2]) {
    color("white")
      difference() {
      cube([43.7, 34, 2.9], center = true);
      translate([0, 0, -0.1])
	cube([43.7 - 0.7 * 2, 34 - 0.7 * 2, 2.9], center = true);
    }
  }
  // screen base
  translate([0, 0, -2.5 / 2])
    color("grey")
    cube([43.7 - 0.9 * 2, 34 - 0.9 * 2, 2.5], center = true);

  // screen
  translate([(43.7 - 0.9 * 2 - 38.5) / 2, 0, -2.9 / 2])
    color("black")
    cube([38.5, 34 - 0.9 * 2, 2.9], center = true);
  }

  // sd card slot
  translate([0, -16.9 / 2, 1.6 + 2.5 / 2])
    difference() {
    color("lightgrey")
    cube([21.6, 16.9, 2.5], center = true);
    translate([0, -0.1, 0])
    cube([21.4, 16.9, 2.4], center = true);
  }
}

/*
if ($preview) {
  st7735v1(false);
 }
*/

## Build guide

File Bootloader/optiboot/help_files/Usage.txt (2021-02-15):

Author: Karl-Heinz Kübbeler   (kh_kuebbeler@web.de) , Mai 2016, Jun 2020

This is a assembly language version of optiboot 6.2 !
The required space could be reduced with the same functionality,
so that a support for EEprom read/write could be integrated in 510 Bytes.
Therefore the EEprom support is integrated by default, but you can
also deselect the feature with a option SUPPORT_EEPROM=0 .

The clock rate is preselected for every configurations in the Makefile,
but you can select a different value by setting the option AVR_FREQ=xxxxxx ,
where xxxxxx is the new frequency in cycles per second (Hz).

Example:
***********************************************
make atmega328p AVR_FREQ=8000000 BAUD_RATE=9600
***********************************************
This will generate a bootloader code for a ATmega328P with 8 MHz clock frequency
and a serial communication at 9600 baud.

For a Arduino UNO only the simple call is needed for generating the program data:
***************
make atmega328p
***************
ATmega328P with 16MHz and 115200 Baud.

With the similar call:
*********************
make atmega328p ISP=1
*********************
the optiboot program data will be transferred to the ISP-programmer and additionally
 all fuses are set.
You should know, that the Flash memory content is completely erased before
programming the new bootloader code. Any application program must be programmed
again later with the serial interface.
The ISP-programmer should be set in the Makefile.isp file correctly before you
use any "make  xxx ISP=1" type make call.
Typically the program avrdude is used to transfer the data to the programmer.
A list of sample configurations you can find in the makeall batch file.
The Makefile make use of utilities, which determine the size of the bootloader program
automatically and set the start address and the required fuses right
according to the actual size.

This kind of automatic is tested at a Linux system and should run at any Linux system.
Additionally it is basically tested with Windows10 and the installed Arduino Package
and the Unix-tools package cygwin64.
The cygwin64 package was installed at the path c:\cygwin64 .
For using the additional commands, you must add this path to the Path variable
of the Windows10 system. You find more information about the Windows10 usage
in the file Windows_usage.txt .

This optiboot bootloader is tested with a Arduino-UNO and -Nano board and with 
nearly all supported processors (see the list at the end of this ReadMe2).
Only the AT90CAN64, the ATmega1280/2560, the ATmega16u4 and the ATmega8u2/16u2 are untested.

The optional implementation of a software UART requires a little more space, but should
also match to a 512 Byte boot partition.
Lower baud rates can often better supported with the SOFT_UART option compared to
the hardware UART. Additionally you are free to
select any present port pin for the serial input and output.
With a 20 MHz CPU you can select baud rates of 300 Baud and higher, with lower CPU clock rates
you can even select lower baud rates.
With the hardware solution and a 20 MHz CPU the lowest selectable standard serial rate is 600 baud,
with a 16 MHz CPU you can also select 300 baud.
If your CPU clock rate is sufficient, the standard serial rate of 115200 baud
is a good selection to get a fast transmission. 
For a good CPU clock rate match is also 1 Mbaud possible with the hardware UART.

The VIRTUAL_BOOT_PARTITION feature is only checked with the tested ATtiny processors.
For all processors without a boot partition the option VIRTUAL_BOOT_PARTITION is
set automatically.
Normally the start vector is switched with the fuses (BOOTRST bit) to the
bootloader start address, but this feature is missing at the ATtiny84.
If the VIRTUAL_BOOT_PARTITION is selected, the AVR reset vector
can remain at the application start address (0x0000).
Instead of switching the Reset start address the Reset interrupt vector of the
application program should be changed to the bootloader start address.
The original start address of the application program is moved to another
interrupt vector and will be used later by a bootloader timeout.
For that feature the bootloader try to change the interrupt vectors
during programming the application program and simulates the correct
back read data for a following verify.
The host, which send the data to the bootloader, did not notify the modification.
But the implemented trick will not work for a second separate verify of
the Flash content by the host.
To prevent this, this optiboot saves the modified data in the last two EEprom bytes.
So the later verify will be possible until these EEprom data are overwritten.
I believe, that it will be better to implement this feature by the application 
program itself.
One of the difficulties with the patch is, that for Flash memory space above 8K
the interrupt vector addresses can hold a JMP or also a RJMP instruction!
Currently the bootloader assumes, that only JMP instructions are used in the 
interrupt vector table, if the processor has more than 8 kByte flash memory.

=======================================================================================
Available options
=======================================================================================
AVR_FREQ		specifies the frequency (Hz), at which the AVR micro controller should run.

BAUD_RATE		specifies the baud rate for the serial interface.
			If a value below 100 Baud is specified, optiboot use a
			measurement of the baud rate instead of a fixed baud rate.
			If a baud rate below 60 is specified, a simpler measurement
			is used to save memory.
			If a baud rate below 40 is specified, a additional monitoring
			of the time is omitted with this simpler measurement.

SOFT_UART		With this option you select a software UART solution instead of
			a hardware UART. With the software solutions you are free to select
			any available port pins.

UART_RX			You can specify any input pin available at your chip for serial
			data input with the SOFT_UART option. You must only specify the
			input pin with two characters. The first uppercase alphabetical character
			specifies the Port and the following numeric character specifies
			the bit number of the port (0-7).

UART_TX			You can also select the serial output pin for the SOFT_UART Option.
			The format for selecting the port pin is the same as for the input (RX).
			You can also select different ports for input and output.

UART_RX=UART_TX         If you specify the same pin for RX and TX, the optiboot program
                        will switch this pin automatically between input and output (one wire).
                        The transfer program at your PC must tolerate the additional echo characters
                        or you need a special interface electronic to prevent the echoes.

UART			specifies the hardware UART-interface to use.
			Possible values are 0 to 3, if the selected AVR support several
			hardware UART interfaces. The default number is 0.

LED_START_FLASHES	specifies, how often the LED should flicker, before the serial 
			communication is started. If you specify a 0, no LED output is done.
			If you specify a 1 or -1, the LED Flash only onces without the program loop.
			Negative settings will force a break of the flashing loop by
			incoming RX data.

LED_DATA_FLASH		let the LED light during wait for a serial character input. 

LED			specifies with two characters the port and the bit number (0-7) of
			the LED signal output. 
			The first character is the port code letter (A,B,C,D,E,F,G,H,J,K,L).

C_SOURCE		with this option set to 1 you can select the C-source instead of
			the standard assembler source (optiboot.S).
			The with the C-source generated program requires more Flash memory.

SUPPORT_EEPROM		If you set this value to a nonzero value, the bootloader is created 
			with the EEprom write and read support.
			The assembly version of the bootloader support the EEprom use 
			without the option setting. But you can deselect this feature
			by setting the option to zero (SUPPORT_EEPROM=0).
			You should know, that the Flash memory content can be destroyed
			by using a EEprom write without the EEprom support!

BIGBOOT			This option was earlier required to match the setting of start address
			and AVR fuses to a program size above 512 Bytes.
			The adaption of the correct starting address and the correct setting
			of the AVR fuses is done now automatically.
			But the option is not removed. You can use it now to test the
			automatic adaption or to set the bootloader start address to
			a specific address. The bootloader code will grow for as many
			bytes, as you specify. 500 additional bytes let the size of
			the bootloader grow, so that the bootloader start address
			will change from 0x7e00 to 0x7c00 for example. 

VIRTUAL_BOOT_PARTITION 	this option changes two interrupt vector jmp addresses,
			so that the bootloader is started with the reset vector.
			Another interrupt vector is used to save the original
			start address of the application program.
			The JMP instruction or the target address of the JMP 
			is saved in the last two bytes of the EEprom memory.
			So a verify of the loaded flash data is possible
			as long as this EEprom data are not destroyed by
			the application program.

TIMEOUT_MS		This option specifies a time limit in ms units for receiving boot data. 
			After this time without data the boot process is aborted and it is tried to
			start the user program.
			Possible values for TIMEOUT_MS are 500, 1000, 2000, 4000 and 8000.
			The effective value can be limited to 2 seconds because of processor limits for the watchdog.

OSCCAL_CORR		This option specifies a correction value for the OSCCAL Byte of the AVR-Processor.
			The correction value is only effectual, if the internal RC-oscillator of the AVR processor
			is used, not with the crystal operation.
			Because the produced Baud-rate depends directly of the processor clock,
			a calibrated clock frequency is important for a successful serial data transfer.

FORCE_RSTDISBL		You can set this option to 1, if you plan to set the RSTDISBL feature in the HFUSE.
			The setting of the RSTDISBL bit (to 0) is detected by optiboot and
			the compiling is aborted without the setting of this option. 

NO_EARLY_PAGE_ERASE     The optiboot program does not use the feature, that the flash memory erase
	                can be done during the data receive, if this option is set.
			This will make the write to flash about 30% slower,
                        but you cam probably save 14 bytes of memory for the bootloader code.
                        The loss of speed has even less of an impact in practice, since the data
                        is usually also read back and checked.

Recommendation:
===============
The optiboot loader transfer the original content of the MCUSR register to the application
program in the r2 register. The MCUSR register shows the reason for the reset.
I think, that it would be better to use a AVR hardware IO register like GPIOR0.
For a C application program ist it easier to read the IO-Register content as the content
of any working register (r0-r31).
The GPIORx register has no special function and can therefore used without any restriction.
A additional use of this register by a application program is not prohibited.
For AVR micro controllers without this IO register group the counter register OCR2 is used.

I look forward for any replies to the "assembly language optiboot" subject.

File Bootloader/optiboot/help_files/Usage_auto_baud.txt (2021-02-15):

Author: Karl-Heinz Kübbeler   (kh_kuebbeler@web.de) , Jul 2020

A automatic baud rate determination can be selected by specifying
a BAUD_RATE below 100.

The number of bits used for the baud rate calculation and the use of an additional
check of the received character are determined with each group of ten.
The following list gives you an overview:

Area	 Bits  time limit   data check
10-19	 9	-		-
20-29	 2	-		-
30-39	 4	yes		-
40-49	 2	yes		-
50-59	 4	yes		-
60-69	 2	yes		yes
70-79	 4	yes		yes
80-89	 9	yes		yes

All settings of the baud rate with the last digit in the range 0-4 will select
a 16-Bit counter with a clock divided by factor 8 for time measurements.
The other settings with the last digit between 5 and 9 use a 16-Bit counter
at full CPU clock rate.

All automatic selected baud rates can be used with present hardware UARTs or
with a software solution for the UART.
Of course the optiboot programs with a automatic baud rate selection are
bigger than the programs with a fixed baud rate selection.
The implementation of the software UART will need additional memory,
which will exceed the 512 byte limit in most cases.

The following table give you an overview about the setting options with software UART:

BAUD_RATE	No. of cycles	Resolution	Comment
last digit	delay loop pass	Time measurement

  0		  6/8		  8/CLK		Slow calculation, 8 cycles only for 9 Bit
  1		  10		  8/CLK
  2		   6		  8/CLK
  3		  16		  8/CLK		Increased number of cycles for a loop pass
  4		   8		  8/CLK		Increased number of cycles for a loop pass

  5		  10		  1/CLK		Slow calculation, 8 cycles only for 9 Bit
  5		   6		  1/CLK
  7		  10		  1/CLK
  8		   8		  1/CLK		Increased number of cycles for a loop pass
  9		  16		  1/CLK		Increased number of cycles for a loop pass

With the slow calculation for the pass count of the delay loop (last digit 0 and 5)
for the serial communication the risk is high, that the calculation is too slow to
end before the Stop-Bit has finished and the transmission of next Rx data has already
started without preparing the receiver.
To prevent this situation, the other methods use either an accelerated subtract loop
for the division or shift instructions if the divisor is a power of two.
The use of shift instruction for the division can be easier done with the increased
number of cycles for a loop pass (last digits 3,4,8,9).
Unfortunately, the solution with the shift commands only results in the shorter program
if no more than 2 shift operations are needed.

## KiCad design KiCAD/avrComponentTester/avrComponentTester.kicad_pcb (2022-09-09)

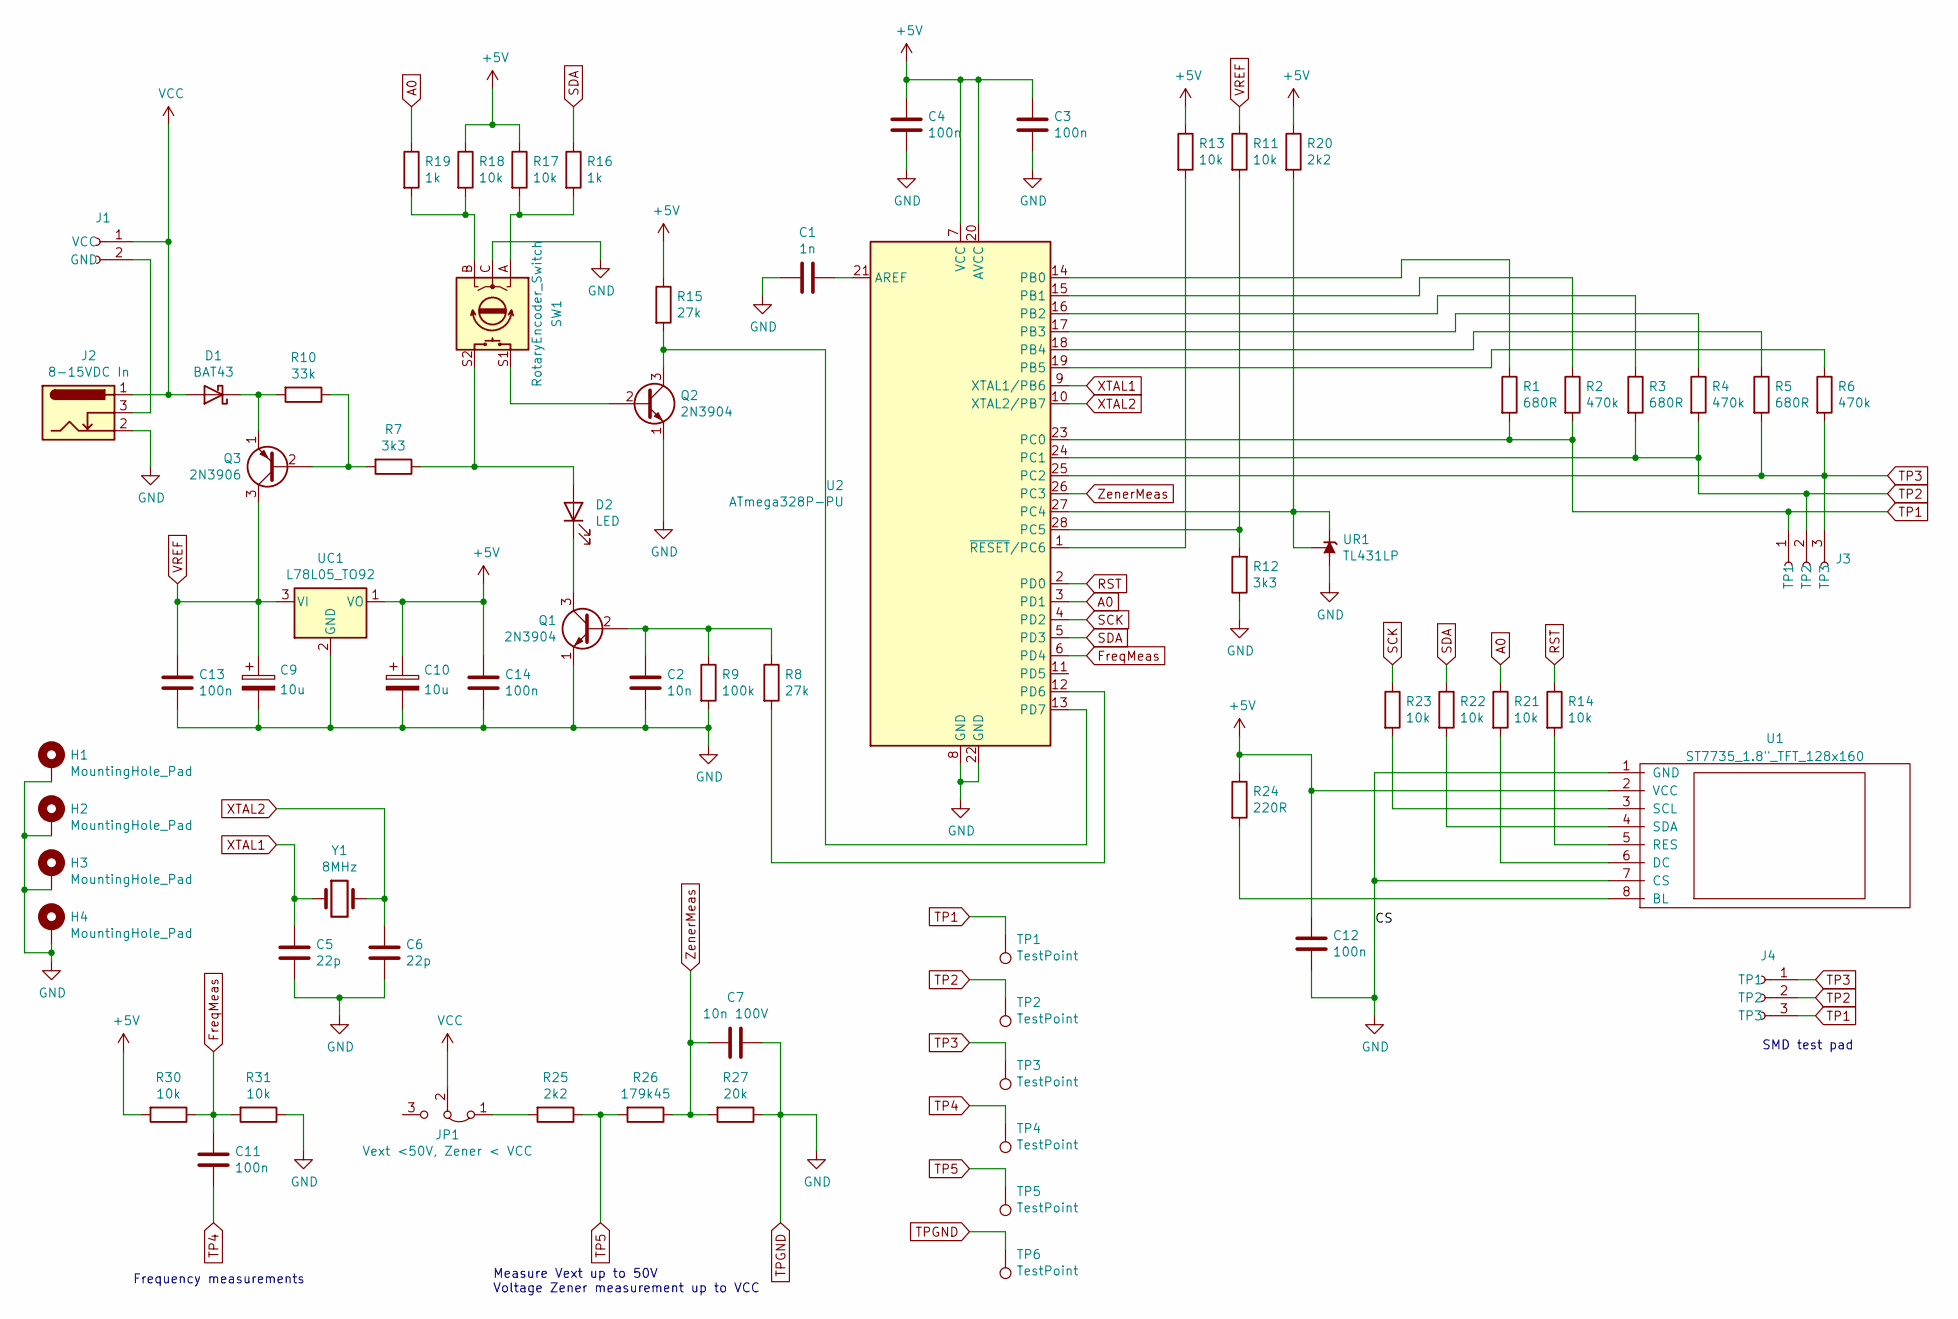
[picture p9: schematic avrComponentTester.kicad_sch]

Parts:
C1: 1n; C_Disc_D3.0mm_W1.6mm_P2.50mm_larg
C2: 10n; C_Disc_D3.8mm_W2.6mm_P2.50mm_large
C3, C4: 100n; C_Disc_D3.0mm_W1.6mm_P2.50mm_larg
C5, C6: 22p; C_Disc_D3.0mm_W1.6mm_P2.50mm_larg
C7: 10n 100V; C_Disc_D7.5mm_W2.5mm_P5.00mm_larger
C9, C10: 10u; CP_Radial_D5.0mm_P2.00mm_larger
C11, C12, C13, C14: 100n; C_Disc_D3.8mm_W2.6mm_P2.50mm_large
D1: BAT43; D_DO-35_SOD27_P7.62mm_Horizontal_large
D2: LED; LED_D5.0mm_larger_pads
H1, H2, H3, H4: MountingHole_Pad; MountingHole_3.2mm_M3_Pad
J1: 2-pin_power_input_header
J2: 8-15VDC In; BarrelJack_Horizontal
J3: 3-pin_test_header; 3-pin_test_header_large
J4: 3-pin_test_header; 3-pad_SMD_test-pad
JP1: Vext <50V, Zener < VCC; Jumper_1x03_P2.54mm_large
Q1, Q2: 2N3904; TO-92_Inline_Wide
Q3: 2N3906; TO-92_Inline_Wide
R1, R3, R5: 680R; R_Axial_DIN0207_L6.3mm_D2.5mm_P10.16mm_Horizontal_larger_pa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
R2, R4, R6: 470k; R_Axial_DIN0207_L6.3mm_D2.5mm_P10.16mm_Horizontal_larger_pa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
R7, R12: 3k3; R_Axial_DIN0207_L6.3mm_D2.5mm_P10.16mm_Horizontal_larger_pa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
R8, R15: 27k; R_Axial_DIN0207_L6.3mm_D2.5mm_P10.16mm_Horizontal_larger_pa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
R9: 100k; R_Axial_DIN0207_L6.3mm_D2.5mm_P10.16mm_Horizontal_larger_pa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
R10: 33k; R_Axial_DIN0207_L6.3mm_D2.5mm_P10.16mm_Horizontal_larger_pa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
R11, R13, R14, R17, R18, R21, R22, R23, R30, R31: 10k; R_Axial_DIN0207_L6.3mm_D2.5mm_P10.16mm_Horizontal_larger_pa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
R16, R19: 1k; R_Axial_DIN0207_L6.3mm_D2.5mm_P10.16mm_Horizontal_larger_pa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
R20, R25: 2k2; R_Axial_DIN0207_L6.3mm_D2.5mm_P10.16mm_Horizontal_larger_pa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
R24: 220R; R_Axial_DIN0207_L6.3mm_D2.5mm_P10.16mm_Horizontal_larger_pa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
R26: 179k45; R_Axial_DIN0207_L6.3mm_D2.5mm_P10.16mm_Horizontal_larger_pa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
R27: 20k; R_Axial_DIN0207_L6.3mm_D2.5mm_P10.16mm_Horizontal_larger_pa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
SW1: RotaryEncoder_Switch; RotaryEncoder_Alps_EC11E-Switch_Vertical_H20mm_large
TP1, TP2, TP3, TP4, TP5, TP6: TestPoint; TestPoint_THTPad_4.0x4.0mm_Drill3.0mm
U1: ST7735_1.8"_TFT_128x160; ST7735_1.8_TFT_display_128x160_large
U2: ATmega328P-PU; DIP-28_W7.62mm_LongPads w socket
UC1: L78L05_TO92; TO-92_Inline_Wide
UR1: TL431LP; TO-92_Inline_Wide
Y1: 8MHz; Crystal_HC49-4H_Vertical_large

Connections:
+5V: C3.1, C4.1, C10.1, C12.1, C14.1, R13.1, R15.1, R17.1, R18.1, R20.1, R24.1, R30.2, U1.2 (VCC), U2.7 (VCC), U2.20 (AVCC), UC1.1 (VO)
A0: R19.1, R21.1, U2.3 (PD1)
FreqMeas: C11.1, R30.1, R31.2, U2.6 (PD4)
unnamed: C1.1, U2.21 (AREF)
unnamed: C2.1, Q1.2 (B), R8.1, R9.1
unnamed: D1.1 (K), Q3.1 (E), R10.2
unnamed: D2.1 (K), Q1.3 (C)
unnamed: D2.2 (A), R7.1, SW1.S2
unnamed: J1.2 (GND), J2.3
unnamed: JP1.1 (A), R25.2
unnamed: Q2.2 (B), SW1.S1
unnamed: Q2.3 (C), R15.2, U2.13 (PD7)
unnamed: Q3.2 (B), R7.2, R10.1
unnamed: R1.1, U2.14 (PB0)
unnamed: R2.1, U2.15 (PB1)
unnamed: R3.1, U2.16 (PB2)
unnamed: R4.1, U2.17 (PB3)
unnamed: R5.1, U2.18 (PB4)
unnamed: R6.1, U2.19 (PB5)
unnamed: R8.2, U2.12 (PD6)
unnamed: R11.2, R12.2, U2.28 (PC5)
unnamed: R13.2, U2.1 (~RESET/PC6)
unnamed: R14.2, U1.5 (RES)
unnamed: R16.2, R17.2, SW1.A
unnamed: R18.2, R19.2, SW1.B
unnamed: R20.2, U2.27 (PC4), UR1.1 (REF), UR1.3 (K)
unnamed: R21.2, U1.6 (DC)
unnamed: R22.2, U1.4 (SDA)
unnamed: R23.2, U1.3 (SCL)
unnamed: R24.2, U1.8 (BL)
RST: R14.1, U2.2 (PD0)
SCK: R23.1, U2.4 (PD2)
SDA: R16.1, R22.1, U2.5 (PD3)
TP1: J3.1 (TP1), J4.3 (TP3), R1.2, R2.2, TP1.1, U2.23 (PC0)
TP2: J3.2 (TP2), J4.2 (TP2), R3.2, R4.2, TP2.1, U2.24 (PC1)
TP3: J3.3 (TP3), J4.1 (TP1), R5.2, R6.2, TP3.1, U2.25 (PC2)
TP4: C11.2, TP4.1
TP5: R25.1, R26.2, TP5.1
TPGND: C1.2, C2.2, C3.2, C4.2, C5.2, C6.2, C7.1, C9.2, C10.2, C12.2, C13.2, C14.2, H1.1, H2.1, H3.1, H4.1, J2.2, Q1.1 (E), Q2.1 (E), R9.2, R12.1, R27.1, R31.1, SW1.C, TP6.1, U1.1 (GND), U1.7 (CS), U2.8 (GND), U2.22 (GND), UC1.2 (GND), UR1.2 (A)
VCC: D1.2 (A), J1.1 (VCC), J2.1, JP1.2 (C)
VREF: C9.1, C13.1, Q3.3 (C), R11.1, UC1.3 (VI)
XTAL1: C5.1, U2.9 (XTAL1/PB6), Y1.1
XTAL2: C6.1, U2.10 (XTAL2/PB7), Y1.2
ZenerMeas: C7.2, R26.1, R27.2, U2.26 (PC3)

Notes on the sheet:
SMD test pad
Measure Vext up to 50V Voltage Zener measurement up to VCC
Frequency measurements

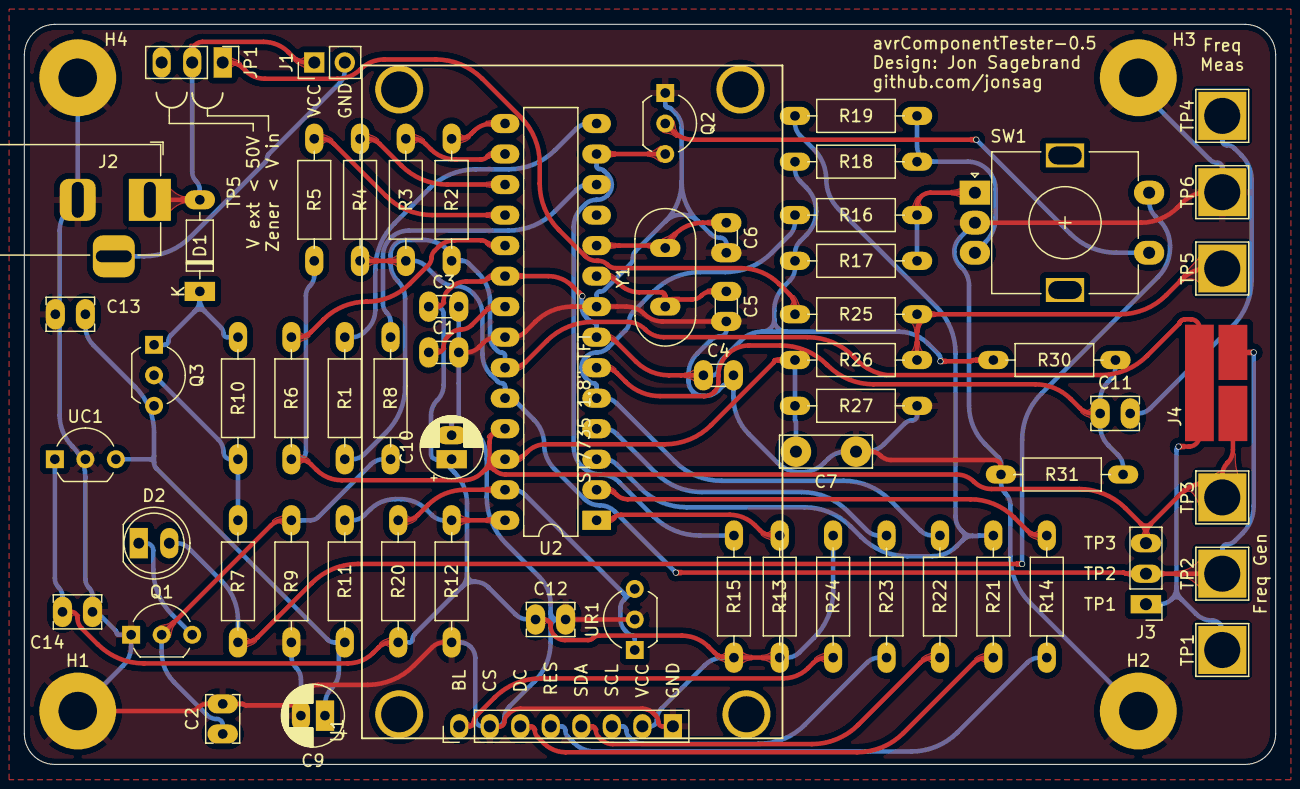
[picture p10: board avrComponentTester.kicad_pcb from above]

Board: 2 copper layers, 104.1 x 61.6 mm, 68 parts (0 on the bottom side), 44 nets.

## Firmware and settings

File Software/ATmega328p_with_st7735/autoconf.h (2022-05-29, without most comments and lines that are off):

#if ((LCD_ST_TYPE == 7565) || (LCD_ST_TYPE == 1306) || (LCD_ST_TYPE == 7108) || (LCD_ST_TYPE == 7920) || (LCD_ST_TYPE == 7735) || (LCD_ST_TYPE == 9163) || (LCD_ST_TYPE == 9341) || (LCD_ST_TYPE == 1327))
 #if ((SCREEN_HEIGHT > 128) && (SCREEN_WIDTH > 255))
  #define ONE_B 16
 #else
  #define ONE_B 8
 #endif
 #define WITH_GRAPHICS 1
 #undef PAGES_PER_LINE
 #define PAGES_PER_LINE ((FONT_HEIGHT + 7) / 8)
 #undef LCD_LINES
 #define LCD_LINES ((SCREEN_HEIGHT/ONE_B) / PAGES_PER_LINE)
 #undef LCD_LINE_LENGTH
 #define LCD_LINE_LENGTH (SCREEN_WIDTH / (ONE_B/8) / FONT_H_SPACE )
 #define TEXT_RIGHT_TO_ICON ((ICON_WIDTH + 16 + 5 + 7) / FONT_H_SPACE)
#elif (LCD_ST_TYPE == 8812)
 #define ONE_B 8
 #define WITH_GRAPHICS 1
 #undef PAGES_PER_LINE
 #define PAGES_PER_LINE ((FONT_HEIGHT + 7) / 8)
 #undef LCD_LINES
 #define LCD_LINES ((SCREEN_HEIGHT/8) / PAGES_PER_LINE)
 #undef LCD_LINE_LENGTH
 #define LCD_LINE_LENGTH (SCREEN_WIDTH / FONT_H_SPACE)
 #define TEXT_RIGHT_TO_ICON ((ICON_WIDTH + 16 + 5 + 7) / FONT_H_SPACE)
#elif (LCD_ST_TYPE == 8814)
 #define ONE_B 8
 #define WITH_GRAPHICS 1
 #undef PAGES_PER_LINE
 #define PAGES_PER_LINE ((FONT_HEIGHT + 7) / 8)
 #undef LCD_LINES
 #define LCD_LINES ((SCREEN_HEIGHT/8) / PAGES_PER_LINE)
 #undef LCD_LINE_LENGTH
 #define LCD_LINE_LENGTH (SCREEN_WIDTH / FONT_H_SPACE)
 #define TEXT_RIGHT_TO_ICON ((ICON_WIDTH + 16 + 5 + 7) / FONT_H_SPACE)
#else
 #define TEXT_RIGHT_TO_ICON 0
  #define FONT_HEIGHT 8
#endif
 #define LCD_ST7565_H_OFFSET 0
 #define LCD_ST7565_Y_START  0
#if LCD_ST7565_Y_START >= SCREEN_HEIGHT
 #warning LCD_ST7565_Y_START is set higher than SCREEN_HEIGHT!
#endif
#ifndef LCD_LINE_LENGTH
 #define LCD_LINE_LENGTH 16
#endif
#if (defined(WITH_GRAPHICS) && (((SCREEN_WIDTH-(TEXT_RIGHT_TO_ICON*FONT_H_SPACE))/FONT_H_SPACE) < 9))
 #define LOW_H_SPACE 1
#else
 #define LOW_H_SPACE 0
#endif
#if (LCD_ST_TYPE != 7920)
#define lcd_refresh()
#endif
#if (LCD_LINES < 2)
 #warning LCD_LINES is not correctly set!
 #if (SCREEN_HEIGHT < 32)
  #warning SCREEN_HEIGHT is not correctly set!
 #endif
 #if (FONT_HEIGHT < 8)
  #warning FONT_HEIGHT is not correctly set!
 #endif
#endif
#if (LCD_LINES < 7) && defined(WITH_6_SELECTION_MENU)
 #warning Display has not sufficient count of lines for WITH_6_SELECTION_MENU !
 #undef WITH_6_SELECTION_MENU
#endif
#if (PROCESSOR_TYP == 8) || (PROCESSOR_TYP == 168) || (PROCESSOR_TYP == 328)
 #if FLASHEND > 0x1fff
  #ifdef TQFP_ADC6
    #undef TPext
    #define TPext ((1<<MUX2) | (1<<MUX1))
    #ifdef TQFP_ADC7
      #define TPex2 ((1<<MUX2) | (1<<MUX1) | (1<<MUX0))
    #endif
  #else
    #ifdef TQFP_ADC7
      #undef TPext
      #define TPext ((1<<MUX2) | (1<<MUX1) | (1<<MUX0))
    #else
     #if (WITH_UART != 0) && (WITH_VEXT != 0)
      #warning "WITH_VEXT deselected, PC3 is used for UART"
      #undef WITH_VEXT
     #endif
    #endif
  #endif
 #else
  #ifndef BAT_CHECK
    #ifdef TQFP_ADC6
      #undef TPext
      #define TPext ((1<<MUX2) | (1<<MUX1))
    #endif
    #ifdef TQFP_ADC7
      #undef TPext
      #define TPext ((1<<MUX2) | (1<<MUX1) | (1<<MUX0))
    #endif
    #if (WITH_UART == 1) && (TQFP_ADC6 == 0) && (TQFP_ADC7 == 0) && (WITH_VEXT != 0)
      #warning "WITH_VEXT deselected, PC3 is used for UART"
      #undef WITH_VEXT
    #endif
  #endif
 #endif
#endif
#if BAT_NUMERATOR < BAT_DENOMINATOR
 #warning "Wrong BAT_NUMERATOR / BAT_DENOMINATOR setting!"
#endif
#if EXT_NUMERATOR < EXT_DENOMINATOR
 #warning "Wrong EXT_NUMERATOR / EXT_DENOMINATOR setting!"
#endif
  #define R_L_VAL 6790          // standard value 680 Ohm, multiplied by 10 for 0.1 Ohm resolution
  #define R_H_VAL 46900         // standard value 470000 Ohm, multiplied by 10, divided by 100
#if R_ANZ_MESS < ANZ_MESS
 #undef R_ANZ_MESS
 #define R_ANZ_MESS ANZ_MESS
#endif
#if U_SCALE < 1
 #undef U_SCALE
 #define U_SCALE 1
#endif
#if U_SCALE > 4
 #undef U_SCALE
 #define U_SCALE 4
#endif
 #define REF_L_KORR 50
#ifdef USE_EEPROM
 #define MEM_TEXT EEMEM
 #define lcd_MEM_string(a)  lcd_fix_string(a)
 #if E2END > 0X1FF
  #define MEM2_TEXT EEMEM
  #define MEM2_read_byte(a)  eeprom_read_byte(a)
  #define MEM2_read_word(a)  eeprom_read_word(a)
  #define lcd_MEM2_string(a)  lcd_fix_string(a)
  #define use_lcd_pgm
 #else
  #define MEM2_TEXT PROGMEM
  #define MEM2_read_byte(a)  pgm_read_byte(a)
  #define MEM2_read_word(a)  pgm_read_word(a)
  #define lcd_MEM2_string(a)  lcd_pgm_string(a)
  #define use_lcd_pgm
 #endif
 #define MEM_EEPROM
 #define MEM_read_word(a)  eeprom_read_word(a)
 #define MEM_read_byte(a)  eeprom_read_byte(a)
#else
 #define MEM_TEXT PROGMEM
 #define lcd_MEM_string(a)  lcd_pgm_string(a)
 #define MEM2_TEXT PROGMEM
 #define MEM_read_word(a)  pgm_read_word(a)
 #define MEM_read_byte(a)  pgm_read_byte(a)
 #define MEM2_read_byte(a)  pgm_read_byte(a)
 #define MEM2_read_word(a)  pgm_read_word(a)
 #define lcd_MEM2_string(a)  lcd_pgm_string(a)
 #define use_lcd_pgm
#endif
#if FLASHEND > 0X1FFF
 #define ACALL call
#else
 #define ACALL rcall
#endif
#if PROCESSOR_TYP == 168
  #define MCU_STATUS_REG MCUCR
  #define ADC_COMP_CONTROL ADCSRB
  #define TI1_INT_FLAGS TIFR1
  #define DEFAULT_BAND_GAP 1070
 #if R_H_VAL == 10000
  #define DEFAULT_RH_FAKT 4022      // mega168 1101 mV, 100.0 kOhm
 #else
  #define DEFAULT_RH_FAKT  856      // mega168 1101 mV, 470.0 kOhm
 #endif
  #define LONG_HFE
  #define PIN_RM 196
  #define PIN_RP 221
  #define CC0 36
  #define COMP_SLEW1 4000
  #define COMP_SLEW2 220
  #define C_NULL CC0+CABLE_CAP+(COMP_SLEW1 / (CC0 + CABLE_CAP + COMP_SLEW2))
  #define MUX_INT_REF 0x0e
#elif PROCESSOR_TYP == 328
  #define MCU_STATUS_REG MCUCR
  #define ADC_COMP_CONTROL ADCSRB
  #define TI1_INT_FLAGS TIFR1
  #define DEFAULT_BAND_GAP 1070
 #if R_H_VAL == 10000
  #define DEFAULT_RH_FAKT 4022      // mega328 1101 mV, 100.0 kOhm
 #else
  #define DEFAULT_RH_FAKT  856      // mega328 1101 mV, 470.0 kOhm
 #endif
  #define LONG_HFE
  #define PIN_RM 200
  #define PIN_RP 220
  #define CC0 36
  #define COMP_SLEW1 4000
  #define COMP_SLEW2 180
  #define C_NULL CC0+CABLE_CAP+(COMP_SLEW1 / (CC0 + CABLE_CAP + COMP_SLEW2))
  #define MUX_INT_REF 0x0e
#elif PROCESSOR_TYP == 644
  #define WITH_ROTARY_CHECK
  #define WITH_UJT
  #define WITH_PUT
  #define MCU_STATUS_REG MCUCR
  #define ADC_COMP_CONTROL ADCSRB
  #define TI1_INT_FLAGS TIFR1
  #define DEFAULT_BAND_GAP 1070
 #if R_H_VAL == 10000
  #define DEFAULT_RH_FAKT 4022      // mega1280 1101 mV, 100.0 kOhm
 #else
  #define DEFAULT_RH_FAKT  856      // mega1280 1101 mV, 470.0 kOhm
 #endif
  #define LONG_HFE
  #define PIN_RM 200
  #define PIN_RP 220
  #define CC0 36
  #define COMP_SLEW1 4000
  #define COMP_SLEW2 180
  #define C_NULL CC0+CABLE_CAP+(COMP_SLEW1 / (CC0 + CABLE_CAP + COMP_SLEW2))
  #define MUX_INT_REF 0x1e
#elif PROCESSOR_TYP == 1280
 #ifndef WITH_ROTARY_CHECK
  #define WITH_ROTARY_CHECK
 #endif
  #define MCU_STATUS_REG MCUCR
  #define ADC_COMP_CONTROL ADCSRB
  #define TI1_INT_FLAGS TIFR1
  #define DEFAULT_BAND_GAP 1070
 #if R_H_VAL == 10000
  #define DEFAULT_RH_FAKT 4022      // mega1280 1101 mV, 100.0 kOhm
 #else
  #define DEFAULT_RH_FAKT  856      // mega1280 1101 mV, 470.0 kOhm
 #endif
  #define LONG_HFE
  #define PIN_RM 200
  #define PIN_RP 220
  #define CC0 36
  #define COMP_SLEW1 4000
  #define COMP_SLEW2 180
  #define C_NULL CC0+CABLE_CAP+(COMP_SLEW1 / (CC0 + CABLE_CAP + COMP_SLEW2))
  #define MUX_INT_REF 0x1e
#else
  #define MCU_STATUS_REG MCUCSR
  #define ADC_COMP_CONTROL SFIOR
  #define TI1_INT_FLAGS TIFR
  #define DEFAULT_BAND_GAP 1298		//mega8 1298 mV
 #if R_H_VAL == 10000
  #define DEFAULT_RH_FAKT 3328      // mega8 1298 mV, 100.0 kOhm
 #else
  #define DEFAULT_RH_FAKT  740      // mega8 1250 mV, 470.0 kOhm
 #endif
  #define LONG_HFE
  #define PIN_RM 196
  #define PIN_RP 240
  #define CC0 27
  #define COMP_SLEW1 0
  #define COMP_SLEW2 33
  #define C_NULL CC0+CABLE_CAP+(COMP_SLEW1 / (CC0 + CABLE_CAP + COMP_SLEW2))
  #define MUX_INT_REF 0x0e
  #define INHIBIT_SLEEP_MODE
  #warning "SLEEP_MODE not possible with mega8"
#endif
 #define REF_R_KORR 0
 #define REF_C_KORR 0
#ifdef POWER_OFF
 #if (POWER_OFF+0) > 2
  #define OFF_WAIT_TIME SHORT_WAIT_TIME
 #else
  #define OFF_WAIT_TIME (LONG_WAIT_TIME - 1)
 #endif
#else
 #define OFF_WAIT_TIME  (LONG_WAIT_TIME - 1)
#endif
#define F_ADC 200000
#if F_CPU/F_ADC <= 2
 #define TICS_PER_ADC_CLOCK 2
 #define AUTO_CLOCK_DIV ((0<<ADPS2) | (0<<ADPS1) | (1<<ADPS0))
#elif F_CPU/F_ADC <= 4
 #define TICS_PER_ADC_CLOCK 4
 #define AUTO_CLOCK_DIV ((0<<ADPS2) | (1<<ADPS1) | (0<<ADPS0))
#elif F_CPU/F_ADC <= 8
 #define TICS_PER_ADC_CLOCK 8
 #define AUTO_CLOCK_DIV ((0<<ADPS2) | (1<<ADPS1) | (1<<ADPS0))
#elif F_CPU/F_ADC <= 16
 #define TICS_PER_ADC_CLOCK 16
 #define AUTO_CLOCK_DIV ((1<<ADPS2) | (0<<ADPS1) | (0<<ADPS0))
#elif F_CPU/F_ADC <= 32
 #define TICS_PER_ADC_CLOCK 32
 #define AUTO_CLOCK_DIV ((1<<ADPS2) | (0<<ADPS1) | (1<<ADPS0))
#elif F_CPU/F_ADC <= 64
 #define TICS_PER_ADC_CLOCK 64
 #define AUTO_CLOCK_DIV ((1<<ADPS2) | (1<<ADPS1) | (0<<ADPS0))
#else
 #define TICS_PER_ADC_CLOCK 128
 #define AUTO_CLOCK_DIV ((1<<ADPS2) | (1<<ADPS1) | (1<<ADPS0))
#endif
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

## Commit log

2021-02-14 More CADs
    [avrComponentTester-Jose_Miquel.kicad_pcb, avrComponentTester-Jose_Miquel.sch, avrComponentTester_Markus_HW-1.00m.kicad_pcb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]
2021-02-15 KiCAD correction :-(
    [avrComponentTester-Jose_Miquel_2-layer.sch]
2021-02-15 New PCB and some READMEs
    [MCU checks.ods, avrComponentTester-Jose_Miquel.kicad_pcb, avrComponentTester-Jose_Miquel.sch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]
2021-04-25 casing, gerber and pcb
    [avrComponentTester-Jose_Miquel_2-layer.kicad_pcb, casing.scad, casing_bottom.stl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]
2022-05-29 deletions and moving to new kicad dir
    [avrComponentTester-Jose_Miquel.kicad_pcb, avrComponentTester-Jose_Miquel.kicad_sch, avrComponentTester-Jose_Miquel_2-layer.csv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]
2022-09-09 kicad, readme
    [avrComponentTester.kicad_pcb, avrComponentTester.kicad_sch]

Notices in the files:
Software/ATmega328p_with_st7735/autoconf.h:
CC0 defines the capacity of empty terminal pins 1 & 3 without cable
